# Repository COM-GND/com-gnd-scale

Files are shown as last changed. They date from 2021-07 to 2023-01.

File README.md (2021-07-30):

COM GND Logo

# COM-GND SCALE

This hardware project is under active development in conjunction with the [GND-CTRL](https://github.com/COM-GND/gnd-ctrl-web-app) software interface.

---

### WARNING: ALPHA STAGE PROJECT

This project is unstable and undergoing active development.

---

## Hardware Stack

- [Esp32 DevkitC](https://www.amazon.com/Espressif-ESP32-DevKitC-32UE-Development-Board/dp/B087T94ZH9): Microcontroller with onboard BLE

## Development

This is a [Platform.io](https://platformio.org/) based project using the Arduino framework.

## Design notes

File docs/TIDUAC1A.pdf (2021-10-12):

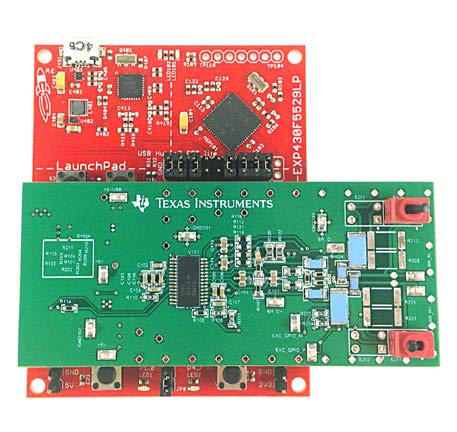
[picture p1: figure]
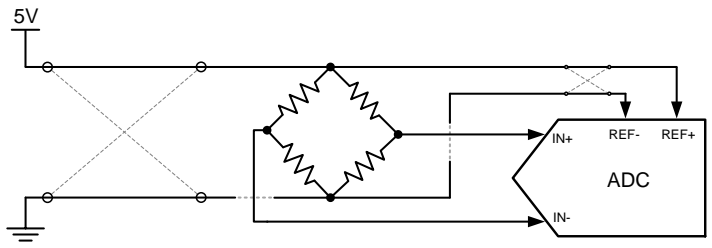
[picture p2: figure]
ADC; REF-; REF+

An IMPORTANT NOTICE at the end of this TI reference design addresses authorized use, intellectual property matters and other important disclaimers and information.
TINA-TI is a trademark of Texas Instruments
WEBENCH is a registered trademark of Texas Instruments
TIDUAC1A-July 2015-Revised February 2019 | Precision Weigh-Scale Reference Design with AC Bridge Excitation | 1
| Copyright © 2015, Texas Instruments Incorporated

Christopher Hall

## TI Designs – Precision: Verified Design

# High-Resolution, Low-Drift, Precision Weigh-Scale Reference Design with AC Bridge Excitation

TI Designs – Precision are analog solutions created by TI’s analog experts. Verified Designs offer the theory, component selection, simulation, complete PCB schematic & layout, bill of materials, and measured performance of useful circuits. Circuit modifications that help to meet alternate design goals are also discussed.

This precision weigh-scale reference design achieves greater than 50,000 noise-free counts of resolution over a wide temperature range. Offset and offset drift errors are nearly eliminated by an ac-excited, ratiometrically measured resistor bridge. This design takes advantage of the high-resolution ADS1262 delta-sigma ADC.

Design Resources
Design Archive (http://www.ti.com/tool/tipd188) | All Design files
TINA-TI™ (http://www.ti.com/tina-ti) | SPICE Simulator
ADS1262 (http://www.ti.com/product/ads1262) | Product Folder
TS5A21366 (http://www.ti.com/product/TS5A21366) | Product Folder
MSP-EXP430F5529LP (http://www.ti.com/tool/MSP-EXP430F5529LP) | Tool Folder

Ask The Analog Experts (http://e2e.ti.com/)
WEBENCH® Design Center (http://www.ti.com/webench)
TI Designs – Precision Library (http://www.ti.com/ww/en/analog/precision-designs/index.html)

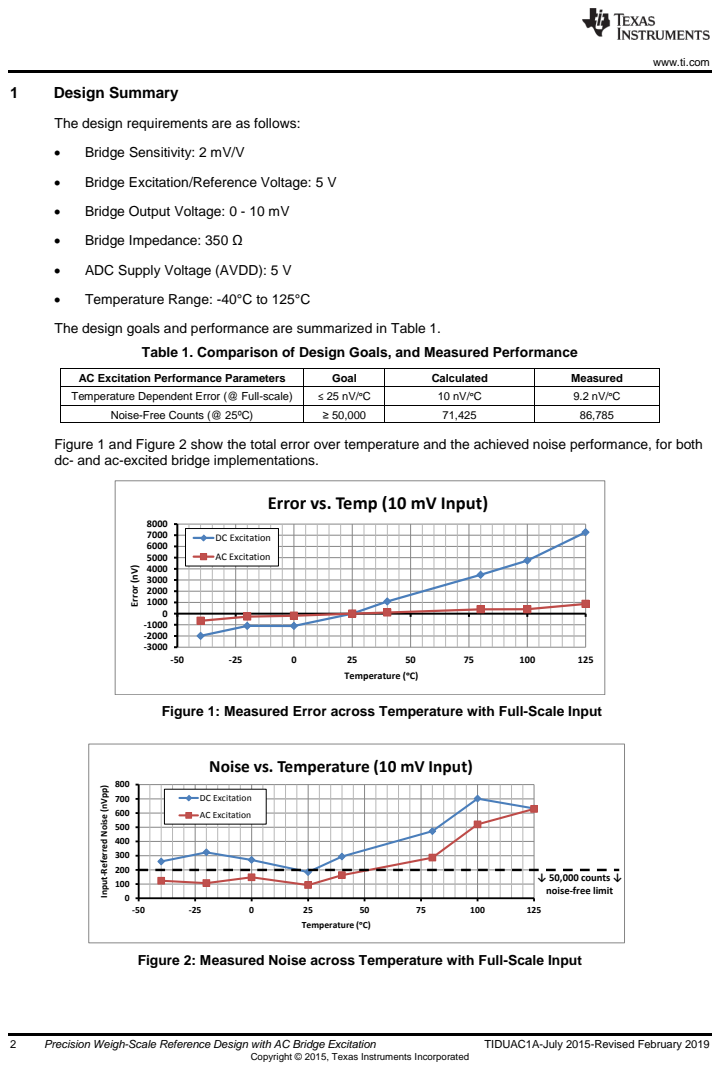
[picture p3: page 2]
Precision Weigh-Scale Reference Design with AC Bridge Excitation; TIDUAC1A-July 2015-Revised February 2019; Error (nV); Temperature (ᵒC); DC Excitation AC Excitation

www.ti.com

1 Design Summary
The design requirements are as follows:
• Bridge Sensitivity: 2 mV/V
• Bridge Excitation/Reference Voltage: 5 V
• Bridge Output Voltage: 0 - 10 mV
• Bridge Impedance: 350 Ω
• ADC Supply Voltage (AVDD): 5 V
• Temperature Range: -40°C to 125°C
The design goals and performance are summarized in Table 1.

Table 1. Comparison of Design Goals, and Measured Performance

AC Excitation Performance Parameters | Goal | Calculated | Measured
Temperature Dependent Error (@ Full-scale) | ≤ 25 nV/ᵒC | 10 nV/ᵒC | 9.2 nV/ᵒC
Noise-Free Counts (@ 25ºC) | ≥ 50,000 | 71,425 | 86,785

Figure 1 and Figure 2 show the total error over temperature and the achieved noise performance, for both
dc- and ac-excited bridge implementations.

Error vs. Temp (10 mV Input)

DC Excitation
AC Excitation

Figure 1: Measured Error across Temperature with Full-Scale Input

Noise vs. Temperature (10 mV Input)

Input-Referred Noise (nVpp)

↓ 50,000 counts ↓
noise-free limit

Figure 2: Measured Noise across Temperature with Full-Scale Input

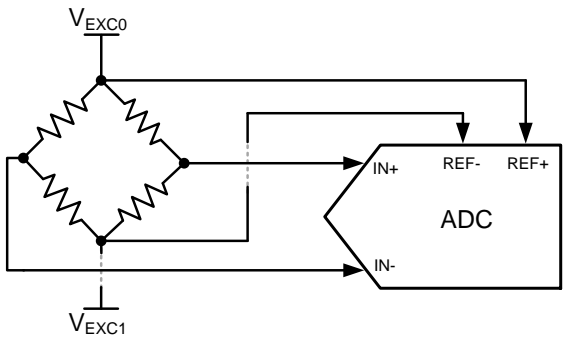
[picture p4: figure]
ADC; REF-; REF+; VEXC0; VEXC1

TIDUAC1A-July 2015-Revised February 2019 | Precision Weigh-Scale Reference Design with AC Bridge Excitation | 3

### 2 Theory of Operation

### 2.1 Overview of Bridge Measurements

The most common technique to convert weight into an electrical signal is to use a resistive load cell configured as a Wheatstone bridge. In this configuration, one or more of the resistors change value in proportion to the load (weight) applied. To measure this effect, an excitation voltage (or current) source is applied across the top and bottom of the bridge and the output signal is measured as the differential voltage across the middle nodes, as shown in Figure 3.

Figure 3: Wheatstone Bridge In practice, load cells are specified with a known sensitivity (or rated output) and a rated capacity (maximum load). The sensitivity is specified by the ratio of the output voltage produced per 1-V excitation voltage (given in units of mV/V) with the rated capacity load applied. The full-scale output voltage of the load cell is then calculated by Equation 1.

# VBBBBBB_FF(m ) = SSSSSSSSSSS

m

# V ∙ VEEE(V) ( 1 )

For example, a 2 mV/V load cell excited with 5 V will have a full-scale output voltage of 10 mV. It is important to note that the magnitude of the output signal is directly proportional to the magnitude of the excitation voltage and applied load. In general, the output voltage for any other applied load will scale linearly from no load to the maximum load. (Bridge linearization techniques may be used increase the bridge linearity, but this topic is outside the scope of this TI Design).

### 2.1.1 Ratiometric Bridge Measurements

The voltage-excited bridge is connected to the ADC using a ratiometric connection, as shown in Figure 4.

Figure 4: Ratiometric Bridge Configuration NOTE: The excitation voltage (VEXC = VEXC0 – VEXC1) does not necessarily need to be referenced to ground. This allows for level-shifting of the bridge common-mode voltage.

Excitation Voltage, VEXC

+
Load Cell
Output Voltage, VOUT

R1
R3 R2

R4

4 | Precision Weigh-Scale Reference Design with AC Bridge Excitation | TIDUAC1A-July 2015-Revised February 2019

In this configuration, the bridge excitation voltage is shared with the ADC’s reference voltage. Any changes in the bridge excitation voltage, due to temperature drift or noise, will affect both the input signal and reference proportionately. Therefore, the ADC conversion results (codes) remain unaffected by changes in the excitation/reference voltage, as shown by Equation 2.

# CCC ∝

# VBBBBBB

VR

# = (% RR L ) ∙ (SSSSSSSSSSS) ∙ VR

VR

# = (% RR L ) ∙ (SSSSSSS ) ( 2 )

Another benefit of ratiometric bridge measurements is that reference noise is reduced because the reference noise is common to both the ADC and reference inputs. To the degree that the reference noise seen by the ADC input and reference terminals match, reference noise is ratiometrically removed from the ADC conversion results, as Equation 2 shows. Therefore, input and reference filters ought to be matched to provide the best reference noise rejection (discussed in SBAA201). (http://www.ti.com/litv/pdf/sbaa201)

### 2.2 Input Chopping Overview

Chopping is a form of averaging that samples a differential input from both directions and averages the conversion results. Figure 5 shows the two phases of an ADC sampling a chopped input, with system offset voltages modelled as VOS1 and VOS2.

Figure 5: Input Chopping Concept

Many high-resolution ADCs, such as the ADS1262, integrate input chopping into the device to reduce the offset and offset drift of the ADC. By performing the chopping operation, any systematic offsets that occur after the chopping circuitry (primarily the ADC’s offset) are removed, as shown by equation 3.

# VAA = VAA (PPP P1) − VAA (PPP P2)

2 | = (VII + VO 1 + VO 2) − (−VII − VO 1 + VO 2)
2 | = VII + VO 1 ( 3 )

Systematic offsets that occur before the input chopping circuitry (represented by VOS1) are not removed by chopping. These offsets are seen as part of the differential input signal and are only removed by offset calibration. However, slowly changing offsets that occur after the chopping (represented by VOS2) are dynamically removed.
NOTE: This design does not use the ADC’s input chopping feature. This discussion is provided only to introduce the input chopping concept and how it works, as a prerequisite for understanding ac bridge excitation.

ADC

ADC

+
–

+
–

VOS2

VIN

VOS2

VADC

+
–

VADC

+
–

IN+

IN-

IN+

IN-

PHASE 1

PHASE 2

VOS1

+
–

+
–

VIN

VOS1

+
–

+
–

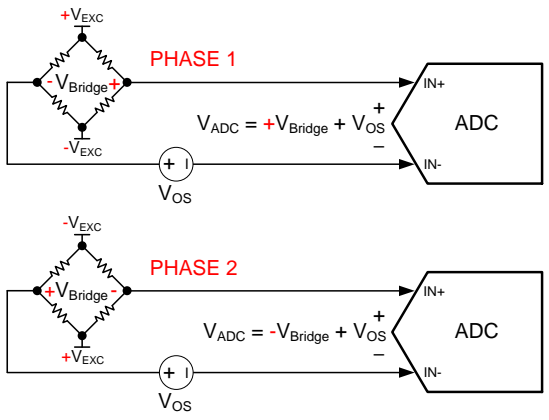
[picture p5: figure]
ADC; +VEXC; VADC = +VBridge + VOS; PHASE 1; -VBridge+; -VEXC; VADC = -VBridge + VOS; PHASE 2; +VBridge -; VOS

TIDUAC1A-July 2015-Revised February 2019 | Precision Weigh-Scale Reference Design with AC Bridge Excitation | 5

### 2.2.1 Overview of AC Bridge Excitation

AC bridge excitation is an extension of input chopping. While input chopping only reduces the offset and offset drift of the ADC; ac bridge excitation reduces the offset and offset drift of the whole measurement system. AC bridge excitation performs the same operation as ADC input chopping, but performs the chopping directly on the bridge sensor. Recalling the observation from Section 2.2 that offsets after the chopping stage are removed, it is then most beneficial to place the chopping circuitry as close to the sensor output as possible. By doing so, the measurement system’s offset is almost completely removed from the measurement results.
AC bridge excitation does not excite the bridge with an actual ac signal (as the name would seem to imply). AC bridge excitation is performed by applying a dc excitation voltage to the bridge and alternating the polarity of the excitation voltage, as seen in Figure 6.

Figure 6: AC Bridge Excitation Concept

Equation 4 shows that ac bridge excitation removes offsets in the same way that input chopping removes offsets. The only difference between these two methods is the location of the chopping/switching.
( | ) ( | )

Bridge

ADC | ADC | Bridge | OS | Bridge | OS
ADC | V V | PHASE | V | PHASE | V | V | V | V
V | = + | − − | + = − = | 2 | 2
( | 1) | ( | 2) | ( 4 )

The offset voltage, VOS, of Figure 6 comprises all offset voltages in the measurement system. These may include the ADC’s offset, parasitic thermocouples (to be discussed in Section 2.3), or any offsets added by signal conditioning circuitry. Therefore, as long as VOS changes slowly (with respect to the chopping frequency) the system’s offset and offset drift are dynamically removed.
The effect of ac bridge excitation is much like continuously measuring and applying a system offset calibration (removing the overall offset of the measurement system, as opposed to input chopping, which only removes the ADC’s contribution to the system offset).

Note that applying the AC bridge excitation technique will require the reference connections to be switched to keep the reference voltage (as seen by the ADC) positive.

6 | Precision Weigh-Scale Reference Design with AC Bridge Excitation | TIDUAC1A-July 2015-Revised February 2019

### 2.3 Overview of Parasitic Thermocouples

Thermocouples are a very useful and common type of temperature sensor. They are formed by junctions of dissimilar metals. When these junctions are exposed to temperature gradients, a thermal electromotive force (EMF), or Seebeck voltage, is produced as a function of the temperature gradient and the metals involved. When thermocouples are used intentionally, they can provide accurate temperature sensing over a wide temperature range and at a low cost. However, unintentional thermocouples are just as common (if not more) and can greatly reduce the accuracy of precision sensing applications. When used unintentionally, we refer to these thermocouples as parasitic thermocouples.
Refer to previous TI Design documents (SLAU509 (http://www.ti.com/lit/pdf/SLAU509) or TIDU574) (http://www.ti.com/lit/pdf/tidu574) for more detailed descriptions and overviews of thermocouple theory.
Parasitic thermocouples exist in many locations within a circuit. Most connections to the printed circuit board (PCB) will involve multiple dissimilar metals such as copper, tin, lead, nickel, gold, silver, aluminum, etc... The larger the Seebeck coefficient (or sensitivity, expressed in μV/ᵒC) between these junctions, the larger the offset voltage that can be introduced into the circuit as a temperature gradient is formed. The typical thermocouple sensitivity of most dissimilar metals will have a Seebeck coefficient in the range of a few microvolts per degree Celsius (μV/ᵒC). However, thermocouples with sensitivities >500 μV/ᵒC are possible with Copper-Copper Oxide junctions (caused by oxidation).
Parasitic thermocouples add to the offset and offset drift of the measurement system and may significantly degrade the overall system accuracy.

### 2.3.1 Reducing the Effects of Parasitic Thermocouples

PCB layout can reduce the effects of parasitic thermocouples. Symmetrical PCB layouts and differential measurements may help to match parasitic thermocouples and cancel any common-mode offsets. The use of a large (solid) ground plane can also act as a heat sink to remove thermal gradients. By keeping dissimilar metal junctions at a constant temperature, the parasitic thermocouple will not induce any additional Seebeck (offset) voltage because of the law of intermediate metals.
Calibration may also be performed to correct for these offsets under certain conditions; however, dynamically changing environments may result in dynamic offsets, which are difficult to correct for by calibration alone. Even when calibrations are performed at multiple operating temperatures, the effect of parasitic thermocouples may still be observed as an offset drift over temperature.
AC bridge excitation is one of the best methods to remove the effects of parasitic thermocouples. Parasitic thermocouples appear after the chopping stage; therefore, their offset is continuously removed. This is the advantage of ac bridge excitation, as compared to offset calibration, which can only remove the initial offset.

### 2.3.2 Other Causes of Offset and Offset Drift

Parasitic thermocouples are just one example of an offset voltage source with temperature dependence. Another common source of offset voltage and offset drift results from input bias currents, namely input offset currents or differential input currents, when the input bias currents of a differential input pair are mismatched. An offset voltage forms when the differential bias current flows through any input-attached impedance, such as an input filter. The offset voltage will be proportional to the current and impedance, and both of these parameters (current and impedance) will typically have temperature dependence. Additionally, offset and offset drift-like behaviors have been shown (reference) (http://e2e.ti.com/blogs_/b/precisionhub/archive/2013/09/23/why-should-i-give-a-flux) to result from solder flux residues remaining from the PCB assembly process. There residues create parasitic conduction paths within the circuit and result in unpredictable behavior.

TIDUAC1A-July 2015-Revised February 2019 | Precision Weigh-Scale Reference Design with AC Bridge Excitation | 7

### 3 Component Selection and Configuration

### 3.1 ADC Selection – ADS1262 (or ADS1263)

The ADC is the critical component in most measurement systems. While all components may affect the overall measurement system performance, the system accuracy is unlikely to exceed the performance of the ADC. Hence, the ADC is typically selected first.
To determine the resolution required by the measurement system, the full-scale output voltage of the bridge is divided by the desired scale resolution specified in counts, as shown in Equation 5. (The scale requirement is 50,000 counts in this example).

# R RR R R RR = 10 m 50,000 = 200 → log2(50,000) = 15.6 b ( 5 )

The measurement system must be able to accurately resolve signals of at least 200 nV, or approximately15.6 bits. However, in practice, an ADC of much higher resolution must be used to account for the loss of dynamic range that occurs when the input signal is not scaled (level shifted and amplified) to match the ADC’s input range. A 24-bit delta-sigma ADC is usually selected for this type of application.
The ADS1262, a 32-bit delta-sigma ADC, was chosen for this design for its low-noise performance and integrated Programmable Gain Amplifier (PGA). The ADS1262 achieves the resolution required for high-end weigh-scale applications. Additionally, the ADS1262 provides General Purpose Input/Outputs (GPIOs) which may be used to control the switches for ac bridge excitation, a programmable settling delay time that allows large input step changes to settle prior to beginning conversions, and a reference polarity switch that makes it easier to implement ac bridge excitation.

### 3.1.1 Programmable Gain Amplifier (PGA) Configuration

The ADS1262’s integrated low-noise PGA provides gains up to 32 V/V. The highest gain setting, that does not exceed the input voltage range requirements, will typically provide the best noise performance. In this design, the full-scale bridge output voltage is 10 mV; therefore, a gain of 32 V/V may be used. (See Table 4 in the ADS1262 data sheet (SBAS661). (http://www.ti.com/lit/pdf/SBAS661)
NOTE: The ADC’s full-scale range scales with both reference voltage and gain. The full-scale range of the ADS1262 (as used in this design), is shown in Equation 6.

# F = ±VR

# PPP = ±(5 V) 32 V/V = ±156 m ( 312 m ) ( 6 )

NOTE: Many weigh-scale designs typically use gains higher than 32 V/V. However, it is important to note that increasing gain amplifies both the input signal and the amplifier’s noise. The low-noise PGA of the ADS1262 is capable of resolving much smaller signals than most other amplifier or PGA configured with higher gain.

### 3.1.2 Digital Filter Configuration

The default filter configuration for the ADS1262 is an FIR filter with a data rate of 20 SPS. This filter setting was used in this design because it provides simultaneous 50/60Hz line cycle rejection and single-cycle settling behavior. This configuration provides ADC resolutions down to 0.167 nVPP, as shown by Table 1 in the ADS1262 data sheet (SBAS661). (http://www.ti.com/lit/pdf/SBAS661)

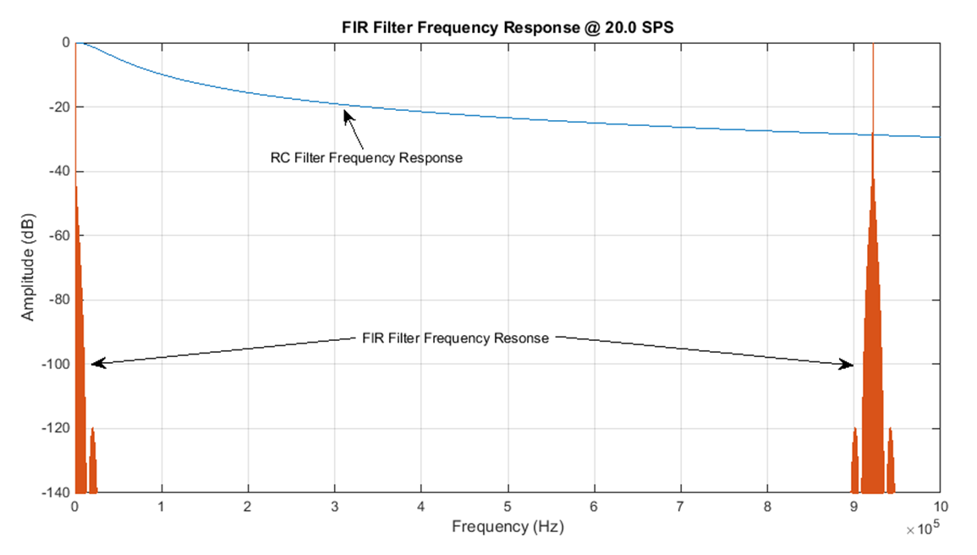
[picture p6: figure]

8 | Precision Weigh-Scale Reference Design with AC Bridge Excitation | TIDUAC1A-July 2015-Revised February 2019

### 3.2 Switch Selection – TS5A21366

The TS5A21366 is a dual single pole single throw (SPST) 0.75Ω analog switch used to control the bridge’s excitation voltage polarity (for ac bridge excitation). This switch was chosen for its voltage compatibility and low on-resistance. The digital logic level of the switch is compatible with the 5-V GPIO logic of the ADS1262, and the input allows for the 5-V bridge excitation voltage. The on-resistance of the bridge switch is important to consider in this application because a significant current flows through the bridge (approximately 15mA. The power dissipation of the bridge switch can cause device heating, as well as reduce the excitation voltage and signal magnitude of the bridge output The TS5A21366 is rated for currents up to 200 mA, making it well suited for this application.

NOTE: The TS5A21366 is only specified to operate from -40ºC to 85ºC and was not directly subjected to the forced ambient air temperatures during testing.

### 3.3 Passive Component Selection

### 3.3.1 Input and Reference Low-Pass Filters

The input and reference filters are first-order RC circuits. The main purpose of the input filter is for anti-aliasing. While this filter can also assist in reducing signal noise, the low-bandwidth digital filter provides the majority of the signal noise rejection; therefore, we are only concerned about using this filter for anti-aliasing.
The aliasing frequencies of concern are frequencies around the modulator sampling frequency, fMOD (for the ADS1262 fMOD = 921.6 kHz when using the internal oscillator). Note that the sampling frequency inside a delta-sigma ADC is much higher than the output data rate. The input signal is oversampled by the delta-sigma modulator and the output data rate is decimated by the digital filter.
The delta-sigma ADC’s digital filter does not provide much noise attenuation around the sampling frequency. Signals in this region are aliased back into the filter’s low-frequency passband. Typically, a single-pole RC filter is adequate to attenuate signals in this region. Figure 7 shows an example of an RC filter with a cutoff frequency of 33.8 kHz and ~29 dB of attenuation near the ADC’s sampling frequency.

Figure 7: 20 SPS FIR Filter Frequency Response Refer to Section 10.1.5.1 in the ADS1262 Data Sheet (SBAS661) (http://www.ti.com/litv/pdf/sbas661) for additional information on aliasing.

TIDUAC1A-July 2015-Revised February 2019 | Precision Weigh-Scale Reference Design with AC Bridge Excitation | 9

### 3.3.2 X2Y™ Capacitors

X2Y™ capacitors were used for the RC low-pass filters. A single X2Y™ capacitor can replace multiple capacitors required for common-mode and differential filtering. In addition to saving board space, these capacitors have low equivalent series inductance (ESL) and excellent common-mode capacitor matching, required to prevent the conversion of common-mode signals to differential signals.
NOTE: Typically common-mode filters become mismatched because of high capacitor tolerances. Higher common-mode signal frequencies are then filtered differently and result in a differential signal seen by the ADC inputs. This effect can also be reduced by ensuring that the differential filter has a lower cutoff frequency (~1/10th) than the common-mode filter’s cutoff frequency.

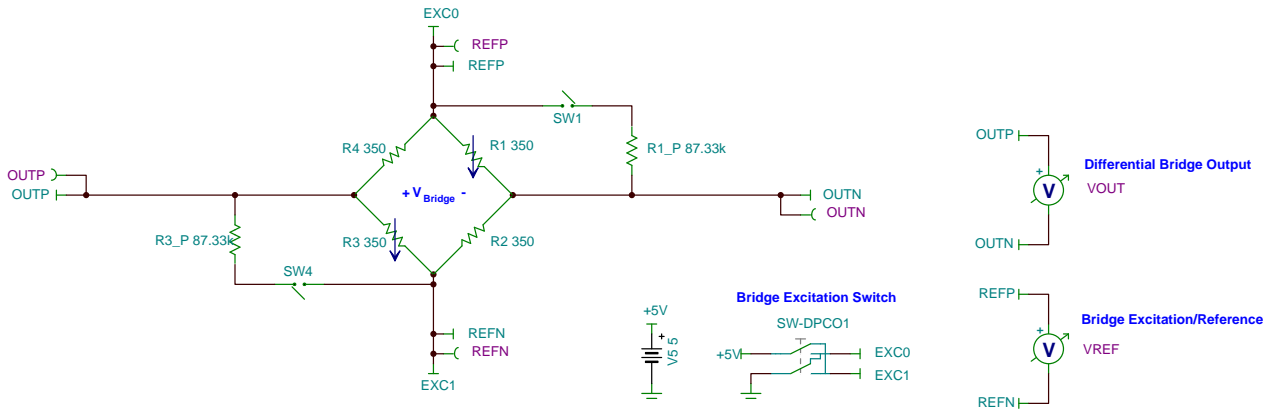
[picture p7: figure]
EXC0; EXC1; EXC0 EXC1; OUTN; OUTP; REFN; REFP; SW-DPCO1; VOUT; VREF; Differential Bridge Output; Bridge Excitation/Reference; Bridge Excitation Switch; + V Bridge -

10 | Precision Weigh-Scale Reference Design with AC Bridge Excitation | TIDUAC1A-July 2015-Revised February 2019

### 4 Simulations and Calculations

### 4.1 Load Cell Bridge Simulator Circuit

Figure 8 shows the TINA-TI™ circuit used to simulate the behavior of the load cell bridge.

Figure 8: Load Cell Bridge Simulator The load cell bridge simulator was designed to model the behavior of a load cell at “no load” and “max load” conditions. When SW1 and SW4 are open, the resistor bridge is balanced and the output voltage should be 0 V (no load condition). When SW1 and SW4 are closed, the resistor bridge is unbalanced and the output voltage should be 10 mV (max load condition with 2 mV/V sensitivity and 5-V excitation). Normally, the resistor changes resistance as a function of the load, but in this simulator circuit, a resistor is switched in to be parallel with the active bridge elements to model the changing resistance. The output voltage of the bridge in Figure 9 can be calculated using Equation 7.

2

2 | R R
V | R V | EXC
Bridge | ∆
+
∆ = − | ⋅ | ( 7 )

Where
- “VEXC ” is the bridge excitation voltage (5 V)
- “ ∆R ” is the change in resistance of R1 and R3 when SW1 and SW4 are closed.
Solving Equation 7 with VBridge = 10 mV, we find that ∆R ≈ -1.3972 Ω. Next we find the value of the parallel resistors (R1P and R3P) that produce an equivalent resistance of R + ∆R and find that parallel resistors of approximately 87.325 kΩ produce the desired outcome. The simulation confirms this result, with a full-scale bridge voltage of 9.97 mV. The 0.3% full-scale error is tolerable because most load cells will have a similar error (which is removed by performing full-scale calibration).

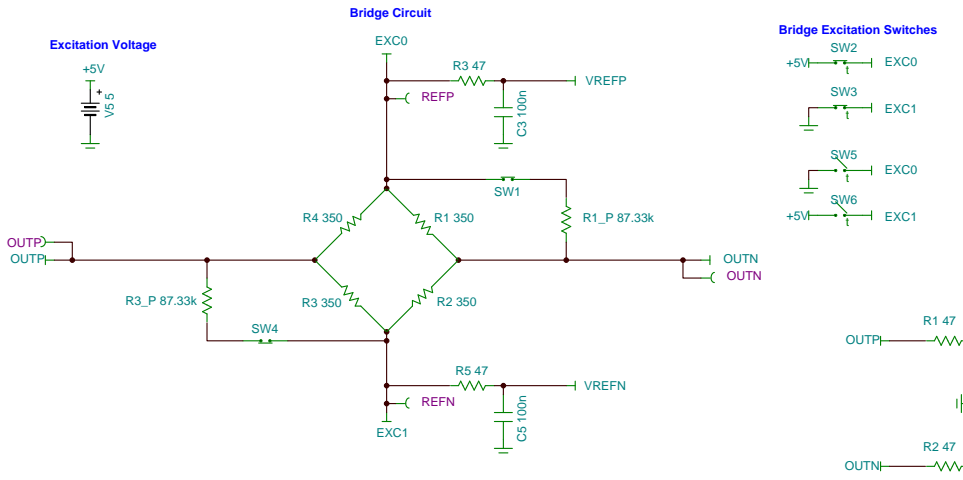
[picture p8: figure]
OUTN; OUTP; EXC0; EXC1; VREFP; VREFN; REFP; REFN; Bridge Excitation Switches; Excitation Voltage; Bridge Circuit
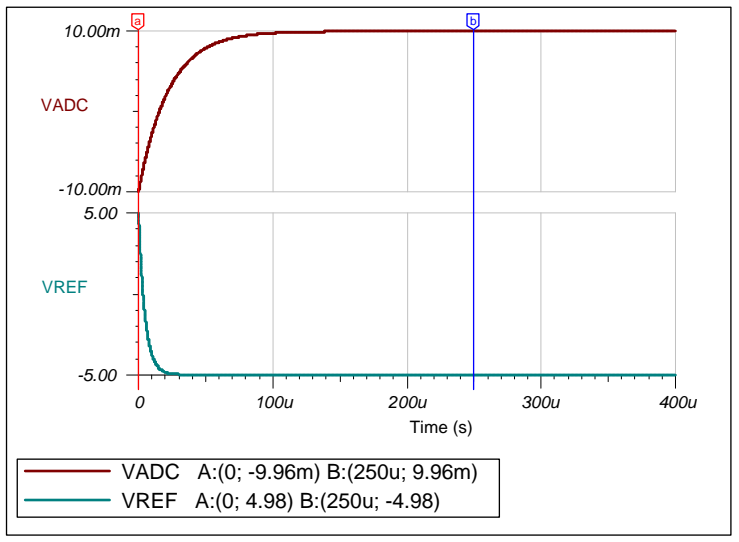
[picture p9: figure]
Time (s); VADC; VREF; VADC A:(0; -9.96m) B:(250u; 9.96m) VREF A:(0; 4.98) B:(250u; -4.98)

TIDUAC1A-July 2015-Revised February 2019 | Precision Weigh-Scale Reference Design with AC Bridge Excitation | 11

### 4.2 Load Cell Simulator Settling Time

Figure 9 shows the TINA-TI™ circuit used to simulate the settling time of the load cell.

Figure 9: Load Cell Bridge Simulator with Low-Pass Filters The circuit in Figure 9 has been slightly modified from Figure 8. Switches SW1 and SW4 are closed to set the bridge to full-scale, time-controlled switches are added to control the bridge excitation polarity, and the RC low-pass filters are included on the reference and bridge outputs.
At a certain time, the bridge excitation polarity is switched in a break-before-make scheme and the bridge output is monitored to observe the required settling time of the RC filter. Note that this settling time needs to be provided each time the ac bridge excitation switches polarity, prior to beginning the ADC conversion, which reduces the effective throughput of the ADC. The transient simulation, shown in Figure 10, shows the combined bridge and filter settling time (observed from the ADC’s input) to be approximately 250 μs.

Figure 10: Bridge Settling Time Transient Analysis Knowing the settling time of the bridge and input circuitry allows us to delay ADC conversions until the ADC’s input signal is settled. The ADS1262 allows for a programmable settling delay. Writing “0110b” to the DELAY[3:0] bits in the MODE0 register configures a 278 µs conversion start delay. See Section 9.4.3 (Programmable Time Delay) in the ADS1262 data sheet (SBAS661). (http://www.ti.com/lit/pdf/SBAS661)

OUTN

OUTP

VREFP

VREFN

V

+
VOUT

V

+
VREF

C1 100n C2 100n
V

+
VADC

Differential Bridge Output

Bridge Excitation/Reference

Differential ADC Input

12 | Precision Weigh-Scale Reference Design with AC Bridge Excitation | TIDUAC1A-July 2015-Revised February 2019

### 4.3 Effective System Data Rate

The effective system data rate, or throughput, is the rate at which ADC data can be read and processed. This data rate may be less than the programmed data rate of the ADC due to certain measurement delays. These delays are discussed for both the dc- and ac-excited bridge measurements.

### 4.3.1 Effective System Data Rate for DC-excited Bridge Measurements

In general, measurements in a dc-excited bridge are taken continuously. Therefore, the effective data rate is the same as the ADC’s configured data rate. Except, the first ADC conversion result includes some conversion latency to allow for the input circuitry to settle and to allow for the conversion results to propagate through the multiple digital filter stages. See Section 9.4.2 in the ADS1262 data sheet (SBAS661). (http://www.ti.com/lit/pdf/SBAS661)
Additionally, post-processing may request multiple ADC samples to calculate an averaged result, further reducing the effective data rate. Once all of these delays are combined, the resulting effective data rate is given by Equation 8.

# DR _EEE = 1

# D Y + ( S ) + (N − 1) DR NN

| ( 8 )
- “D ” is the programmed settling delay of the ADS1262 from the START signal (or command)

to the beginning of ADC conversions. This settling delay should be long enough to account for the analog RC filter settling time as simulated in Section 4.2.
- “ ( S )” is the ADC’s conversion latency for the first conversion period. This period is slightly longer than a normal data rate period to allow for digital delays required to start the conversion, calculate the calibrated results, and output the result. These delays are masked by pipelined operations when continuously converting.
- “DR NN” is the nominal output data rate of the ADC when continuously converting.
- “N” is the number of samples averaged in post-processing.

In this design, the ADS1262 was configured with the 20 SPS, FIR digital filter, and additional 278 µs delay. The time required to collect 16 samples is 802.5 ms, as shown by Equation 9.
1

# DR _EEE

# = D + ( S ) + (N − 1) DR NN

= 278 µ + 52.22 m + (16 − 1)

# (20 S S) = 802.5 m ( 9 )

### 4.3.2 Effective System Data Rate for AC-excited Bridge Measurements

The effective data rate for ac-excited bridge measurements is similar to the dc-excited case; however, the ADC conversion must be restarted every time the excitation voltage is reversed, resulting in additional conversion latency, as shown by Equation 10.

# DRA _EEE = 1

# 2 ∙ D + ( S ) + (N − 1) DR NN

| ( 10 )
- “N”, in this equation, is the number of samples taken each time the excitation voltage polarity is

switched.
In this design, the ac-excited bridge was measured with a total of 32 samples (16 samples each time the bridge excitation voltage was switched), resulting in a total collection time of 1605 ms (twice the time calculated in Equation 10).
NOTE: Software delays are assumed to be insignificant and neglected from Equations 8-10.

TIDUAC1A-July 2015-Revised February 2019 | Precision Weigh-Scale Reference Design with AC Bridge Excitation | 13

### 4.4 Total Error Analysis

The performance of this system depends mostly on the ADC’s performance. The ADS1262 error specifications can be taken from the data sheet (SBAS661) (http://www.ti.com/lit/pdf/SBAS661) and used to estimate the typical performance of this design. The main errors of interest are the noise, offset, offset drift, gain error, gain error drift, and integral nonlinearity (INL). The typical values for these errors were converted to parts per million (ppm) ratios, referenced to the ADC’s full-scale range, as shown in Table 2.
Table 2. Total ADC Error Calculations (Typical)
Typical ADC Errors | Error Before Calibration | Error After Calibration
Noise | 198.00 | (nVpp) | 0.63 | (ppm) | 0.63 | (ppm)
Offset (removed by ac excitation) | 10.9375 | (µV) | 35.00 | (ppm) | 0.16 | (ppm)
Offset Drift (removed by ac excitation) | 10.94 | (nV/ᵒC) | 5.78 | (ppm) | 5.78 | (ppm)
Gain Error | 0.005% | (%) | 1.00 | (ppm) | 0.01 | (ppm)
Gain Error Drift | 0.5 | (ppm/ᵒC) | 5.28 | (ppm) | 5.28 | (ppm)
INL | 3 | (ppm) | 3 | (ppm) | 3 | (ppm)
TOTAL DC Excitation Error Estimate (@ 10 mV) | | | 36.01 | (ppm) | 8.41 | (ppm)
| | | 11253 | nV | 2627 | nV
| | | 14.8 | (nV/ᵒC) | 14.8 | (nV/ᵒC)
TOTAL AC Excitation Error Estimate (@ 10 mV) | | | 6.17 | (ppm) | 6.09 | (ppm)
| | | 1928 | nV | 1903 | nV
| | | 10 | (nV/ᵒC) | 10 | (nV/ᵒC)

For each error calculation, the error was converted to an absolute voltage and then divided by 0.312 mV (the ADC’s full-scale range, as calculated in Equation 6). To estimate the absolute voltage error of a temperature-dependent error (offset drift and gain drift), the error must be multiplied by the temperature range (165ºC in this design). To estimate the absolute voltage error of a gain-related error (gain error and gain error drift), the error is multiplied by the ADC’s full-scale utilization factor (6.4%, or 10 mV divided by 0.312 mV). All errors were added together using the root sum of squares method to calculate the total error. The root sum of squares method assumes all errors are uncorrelated. When calculating the total error for the ac-excited bridge, the offset and offset drift errors were disregarded because they are removed by chopping.
The full Excel spreadsheet with additional error calculations can be found in the TIPD188 design file (TIDCAM8). (http://www.ti.com/lit/zip/tidcam8) ADC error calculations are also explained in a TI Precision Hub Blog (reference). (http://e2e.ti.com/blogs_/b/precisionhub/archive/2014/10/14/adc-accuracy-part-2-total-unadjusted-error-explained)
NOTE: These calculations only take into account the ADC error. The error contributions of the bridge sensor are not observed in this design. In the end-application, the load cell’s linearity and other error contributions should also be considered.
It is apparent from these calculations that the initial offset is the largest source of error. To reduce the offset error, either calibration or ac-excited bridge measurements must be implemented. The next largest sources of error are the offset drift and gain error drift. These errors can only be removed by re-calibrating, limiting the system’s temperature range, or performing ac bridge excitation to remove the offset drift. When ac bridge excitation is used, the ADC may not require calibration (or may not require re-calibration as often). However, in practical use, the load cell introduced errors may still require calibration.
From these calculations, the total measurement error of the ac-excited is estimated to be within 6 ppm (or about 2 µV) across the temperature range. Additionally, the error’s slope across temperature is linearly approximated to be about 15 nV/ᵒC (for the dc-excited bridge), and 10 nV/ᵒC (for the ac-excited bridge).

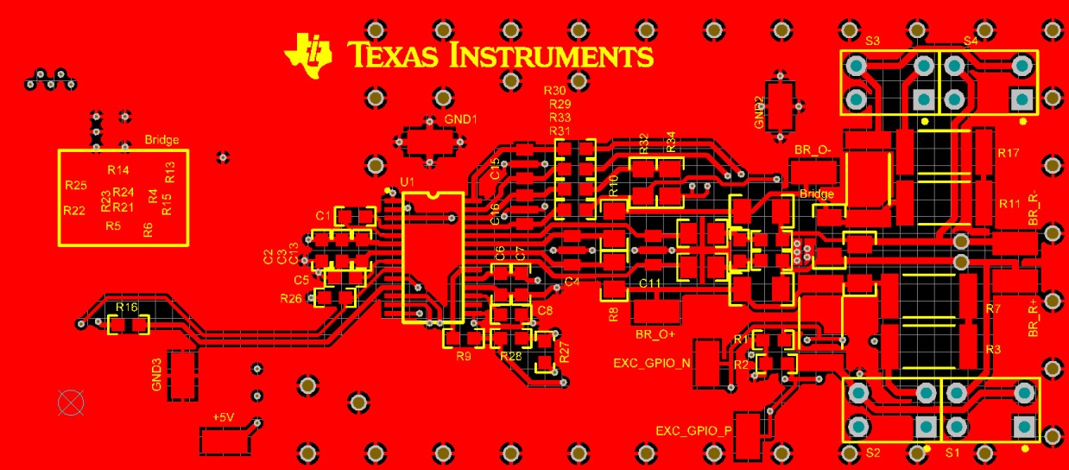
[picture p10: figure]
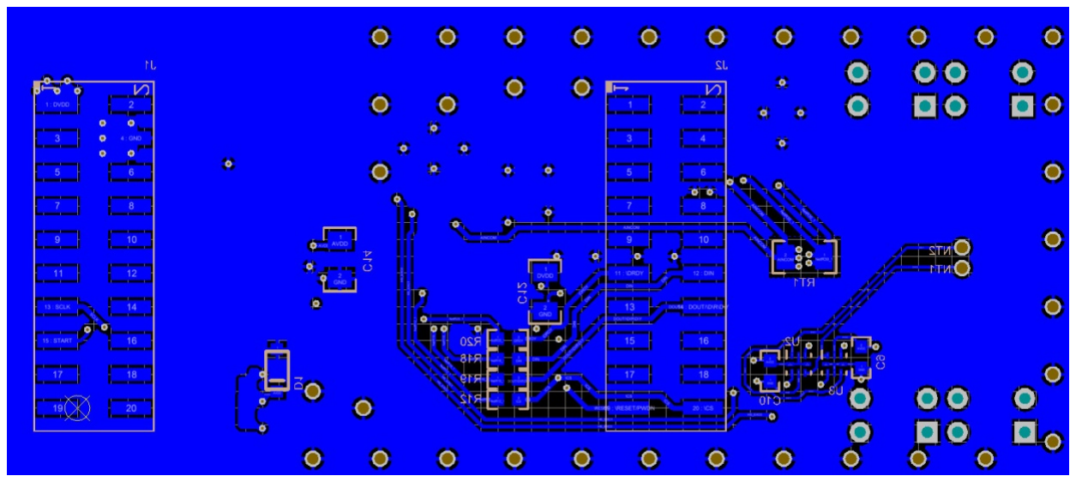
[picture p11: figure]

14 | Precision Weigh-Scale Reference Design with AC Bridge Excitation | TIDUAC1A-July 2015-Revised February 2019

### 5 PCB Design

The PCB schematic and bill of materials can be found in Appendix A.
The PCB is designed in a BoosterPack form factor to connect to TI’s LaunchPads. This particular BoosterPack was specifically designed to pair with the MSP430F5529 USB LaunchPad Evaluation Kit (MSP-EXP430F5529LP). (http://www.ti.com/tool/msp-exp430f5529lp) The LaunchPad provides the SPI interface to the ADS1262 and USB interface to the PC. For LaunchPad Hardware, refer to the MSP-EXP430F5529LP hardware design files (SLAR090). (http://www.ti.com/lit/zip/slar090)

### 5.1 PCB Layout

For optimal performance in any design, follow standard precision PCB layout guidelines including proper power supply decoupling close to all integrated circuits and adequate power and GND connections with large copper pours.
The top and bottom side PCB layout for this design are shown in Figure 11 (inner ground and power layers are not shown). This layout provides proper power supply decoupling and large ground pours on multiple layers. However, this PCB does not provide a symmetrical layout (as discussed in Section 2.3.1) to purposely allow for some parasitic thermocouples effects.

Figure 11: Altium PCB Layout (Top and Bottom Sides)

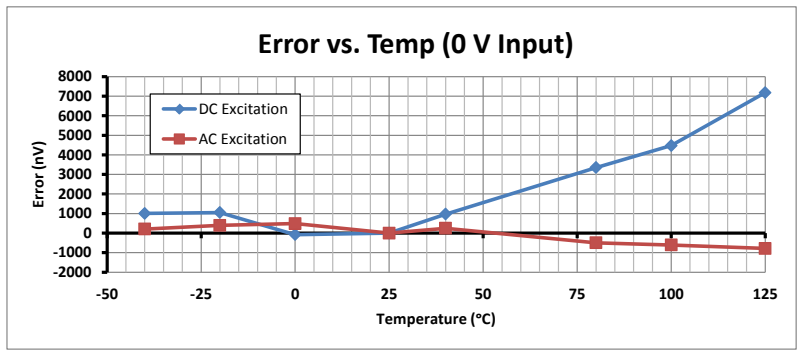
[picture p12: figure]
Error (nV); Temperature (ᵒC); Error vs. Temp (0 V Input); DC Excitation AC Excitation
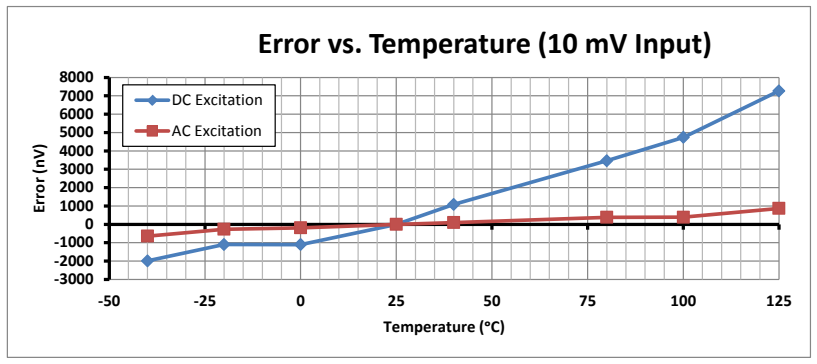
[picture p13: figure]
Error (nV); Temperature (ᵒC); Error vs. Temperature (10 mV Input); DC Excitation AC Excitation

TIDUAC1A-July 2015-Revised February 2019 | Precision Weigh-Scale Reference Design with AC Bridge Excitation | 15

### 6 Verification & Measured Performance

The full data collection procedure is outlined in Appendix C. Measurement data was collected for the 0V input and 10mV input cases. These two cases correspond to the 0% full-scale and 100% full-scale bridge outputs (or 0% and 6.4% full-scale range, with respect to the ADC input range, respectively). These cases typically showcase two extremes of the system performance:
1. Near 0% full-scale, measurement error is dominated by offset and INL errors.
2. Near 100% full-scale, measurement error is dominated by gain errors.

### 6.1 System Measurement Error

The dc and ac bridge excitation measurements were compared to the DMM measurement results to determine the measurement error. The difference between these results removes the offset drift of the resistor bridge circuit from the observed system error. Figure 12 shows the error of the dc- and ac-excited bridge measurements for a 0 V input signal.

Figure 12: Error vs. Temperature (0 V Input)

Similarly, Figure 13 shows the offset drift of the dc and ac-excited bridge measurements for a 10 mV input signal.

Figure 13: Error vs. Temperature (10 mV Input) The measurement error is much improved for the ac-excited bridge. Notice how the absolute values and temperature slope are both reduced. Also, notice that the measurement errors for both the 0V and 10mV inputs signal are very similar. In both of these cases, the offset and offset drift errors dominated the overall measurement error, which is what ac bridge excitation is able to remove.
The total system error for the ac-excited bridge (for a 10 mV input) is within ±1 µV. In Section 4.4, the total error calculated was 2 µV. These correlate well since the measurement error was centered around 25ºC.

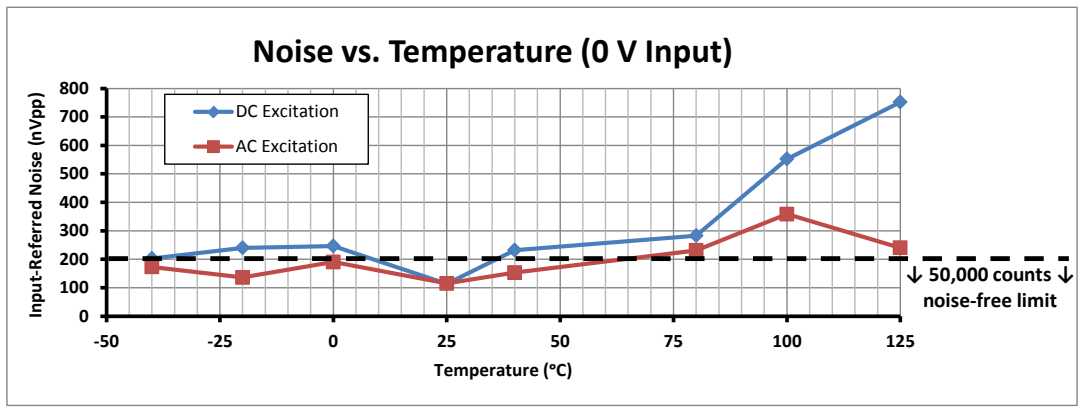
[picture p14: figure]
Input-Referred Noise (nVpp); Temperature (ᵒC); Noise vs. Temperature (0 V Input); DC Excitation AC Excitation; ↓ 50,000 counts ↓ noise-free limit
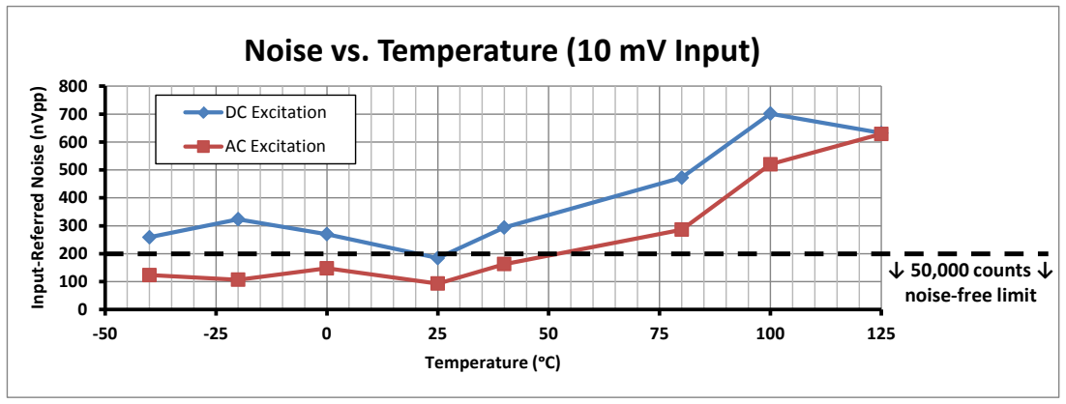
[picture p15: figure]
Input-Referred Noise (nVpp); Temperature (ᵒC); Noise vs. Temperature (10 mV Input); DC Excitation AC Excitation; ↓ 50,000 counts ↓ noise-free limit

16 | Precision Weigh-Scale Reference Design with AC Bridge Excitation | TIDUAC1A-July 2015-Revised February 2019

### 6.2 Noise Performance

The noise performance of the measurement system was observed across temperature and for both load conditions, as shown in Figures 14 and 15. The noise was measured as the maximum peak-to-peak voltage variation observed within 16 samples.
NOTE: For the ac-excited bridge measurements, two samples from opposite excitation polarities were first averaged to reduce the data from 32 samples to 16 (averaged) samples. The noise was then measured as the peak-to-peak voltage variation within the 16 (averaged) samples.

Figure 14: Noise vs. Temperature (0 V Input)

Figure 15: Noise vs. Temperature (10 mV Input) The averaged ac-excited bridge measurements show improved noise performance over the dc-excited bridge measurements and achieved 50,000 noise-free counts of resolution up to about 50 ºC. Noise performance did not degrade significantly from the 0 V to 10 mV input conditions because of the ratiometric measurement configuration, which provides reference noise cancellation.
The number of noise-free counts is calculated using Equation 11.

# N - f c = 10 m

# N ( nn) = 10 m

200 nn = 50,000 ( 11 )

For higher temperatures, increased thermal noise and higher component drift degrade the noise performance. However, weigh-scales are typically not operated up to such high temperatures.

TIDUAC1A-July 2015-Revised February 2019 | Precision Weigh-Scale Reference Design with AC Bridge Excitation | 17

### 7 Modifications

Many times analog circuit design involves trade-offs between various specifications. This section describes some of the trade-off decisions and possible modifications to this TI Design.

### 7.1 Effective Data Rate vs. Noise Performance

It is desirable to operate the measurement system at the fastest (effective) data rate that achieves the required noise performance of the measurement system. Noise performance degrades as the data rate is increased, because at higher data rates, the digital filter bandwidth increases and additional noise is observed in the ADC’s output codes. However, it is not just the programmed data rate that must be considered in this trade-off, but the effective data rate of the system. As seen by Equation 10, the effective data rate is a function of the ADC’s configured output data rate, the total settling and conversion delays, and the number of averages taken for each conversion result.
The portion of time which the ADC is converting must first be maximized to improve both the effective data rate and noise performance of the ADC. Therefore, it is important to keep settling times and conversion delays as small as possible, because the ADC is not converting during these delays. To reduce these delays, the cutoff frequencies of the analog input and reference filters can be relaxed. Even though increasing the cutoff frequencies would seem to degrade the noise performance, it does not have a significant impact at these low data rates, where the digital filter provides the bulk of the noise filtering. The cutoff frequencies of these filters can be increased to provide just enough anti-aliasing, and reducing the required settling time.
NOTE: The analog switch’s settling time may also be reduced by choosing a switch with a higher on-resistance (RON), but lower gate capacitance (Cg). However, the settling time of the switch is usually much smaller than the settling time of the input and reference filters.
Once the ADC conversion time has been maximized, the next option is to determine the number of additional samples to average during post-processing to further reduce the measurement system noise.

Averaging reduces the standard deviation of the noise by a factor of “√N” (“N” is defined in Section 4.3).

Note that the square-root factor provides diminishing returns on noise reduction as the number of averages is increased.

Instead of averaging additional samples (“N”) in post-processing, a better option may be to reduce the

ADC’s data rate. This has a similar effect to averaging multiple samples; however, it also benefits from the delta-sigma ADC’s noise shaping characteristic, resulting in lower noise than averaging in post-processing. For example, reducing the ADC’s data rate from 20 SPS to 2.5 SPS is essentially allowing the ADC to internally average an additional 4 samples per conversion. This typically provides better noise
performance than averaging 4 samples taken at the faster (20 SPS) data rate.

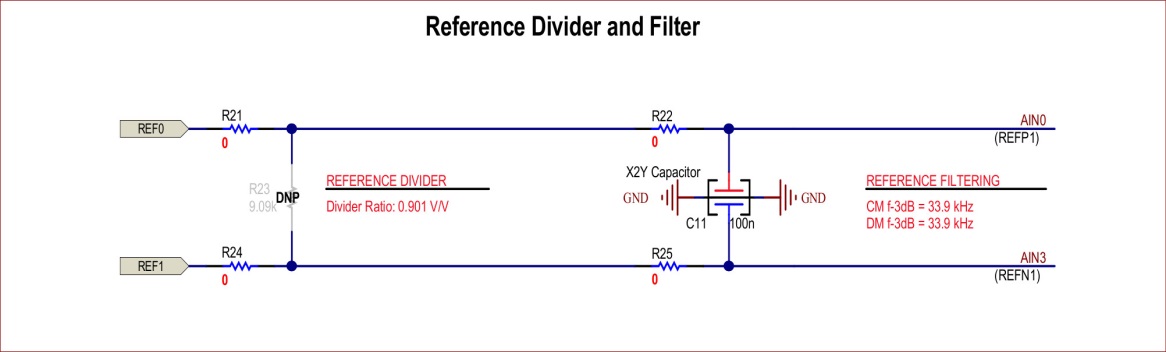
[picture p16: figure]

18 | Precision Weigh-Scale Reference Design with AC Bridge Excitation | TIDUAC1A-July 2015-Revised February 2019

### 7.2 Alternate Reference Filtering Scheme

The schematic for this design provided an optional resistor divider for the ADC’s external reference input. This divider was not used, and all reference filter series resistors (R21, R22, R24, and R25) were populated with 0-Ω resistors, as seen in Figure 16.

Figure 16: Reference Filter When the bridge is excited, the positive reference input is approximately 5 V (AVDD) and the negative reference input is approximately 0 V (AVSS). This leads to an average increase in the reference input bias current of about 50 nA (see the reference in the note below). This input current is also more sensitive to temperature variations. Therefore, any voltage drop across the reference resistors would reduce the reference voltage seen by the ADC, creating an additional gain error and gain error over temperature. This error was avoided by using 0-Ω resistors for the reference filter.
An alternate design option is to populate R21 and R24 with 91-Ω resistors and R23 with a 9.09-kΩ resistor to reduce the ADC’s reference voltage to 4.9 V. This small decrease in reference voltage is enough to avoid the higher reference input bias currents.
NOTE: Figure 33 in the ADS1262 data sheet (SBAS661) (http://www.ti.com/lit/pdf/SBAS661) shows the “Reference Input Current vs Reference Input Voltage”. The input bias current of the positive reference input increases when a 5 V reference is applied. Note that the x-axis step size in this plot is large and that that positive reference input current is well behaved until the reference is very close to 5 V.

### 7.3 Alternate ADC Design Options

The ADS1262 was chosen for this design because of its high performance and features that are well suited for implementing an ac-excited bridge measurement. The ADS1263 is a pin-for-pin and software compatible replacement that adds a secondary 24-bit delta-sigma ADC useful for redundant bridge measurements or other supporting functions within weigh-scale applications.
The ADS1232 and ADS1234 are part of another recommended family of 24-bit delta-sigma ADCs, well suited for bridge measurements. These devices are a lower cost alternative to the ADS126x devices, and are also capable of achieving high repeatability. These ADCs also allow for external references voltages up to AVDD + 0.1 V, which is very useful for implementing ratiometric 5-V excited bridge measurements. For low-power weigh-scale applications, the ADS1220 or ADS1231 24-bit delta-sigma ADCs are recommended. The ADS1220 is capable of fast power-up and duty-cycled operation. Both the ADS1220 and ADS1231provide a low-side bridge switch to power-down the bridge between conversions.

TIDUAC1A-July 2015-Revised February 2019 | Precision Weigh-Scale Reference Design with AC Bridge Excitation | 19

### 8 About the Author

Christopher Hall is an applications engineer in the Precision Delta-Sigma Data Converters group at Texas Instruments where he supports high-resolution industrial and seismic products and applications. Christopher received both his BSEE and MSEE from the University of Arizona.

### 9 Acknowledgements & References

Online Sources:
1. Trump, B. (May 2013). Chopper op amps and noise. http://www.edn.com/electronics-blogs/the-signal/4413341/Chopper-op-amps-and-noise
2. Thermal EMF and Offset Voltage. (April 2010). http://zone.ni.com/reference/en-XX/help/375472A-01/switch/thermal_voltages
3. Williams, Ian (September 2013). Why should I give a flux? http://e2e.ti.com/blogs_/b/precisionhub/archive/2013/09/23/why-should-i-give-a-flux
4. Agarwal, Vinay (October 2014). ADC Accuracy Part 2: Total unadjusted error explained http://e2e.ti.com/blogs_/b/precisionhub/archive/2014/10/14/adc-accuracy-part-2-total-unadjusted-error-explained (http://e2e.ti.com/blogs_/b/precisionhub/archive/2014/10/14/adc-accuracy-part-2-total-unadjusted-error-explained)

TI Documents:
5. ADS126x 32-Bit, Precision, 38-kSPS, Analog-to-Digital Converters with PGA and Voltage Reference. (SBAS661) (http://www.ti.com/lit/pdf/SBAS661)
6. Beckman, M., & Chioye, L. (June 2013). Simple Thermocouple Measurement Solution Reference Design. (SLAU509) (http://www.ti.com/lit/pdf/SLAU509)
7. Thermocouple AFE Using RTD or Integrated Temperature Sensor for Cold Junction Compensation (CJC) (October 2014). (TIDU574) (http://www.ti.com/lit/pdf/tidu574)
8. The ADS1232 and ADS1234: Complete Front End Solutions for Weigh Scales. White Paper. (June 2007). (SBAA154) (http://www.ti.com/lit/pdf/SBAA154)
9. Chioye, Luis. RTD Ratiometric Measurements and Filtering Using the ADS1148 and ADS1248. (March 2013). (SBAA201). (http://www.ti.com/litv/pdf/sbaa201)

www.ti.com

20 Precision Weigh-Scale Reference Design with AC Bridge Excitation TIDUAC1A-July 2015-Revised February 2019

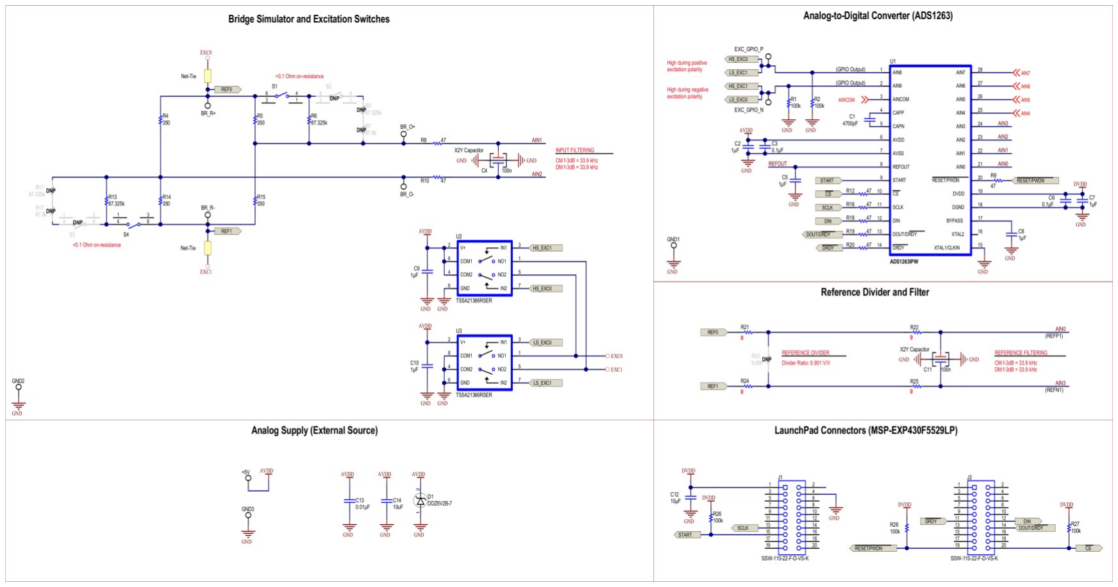
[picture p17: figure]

Copyright © 2015, Texas Instruments Incorporated

### Appendix A. PCB Schematic and Bill of Materials

A.1 Electrical Schematic

The schematic for this design can be seen in Figure A-1.

Figure A-1: Electrical Schematic

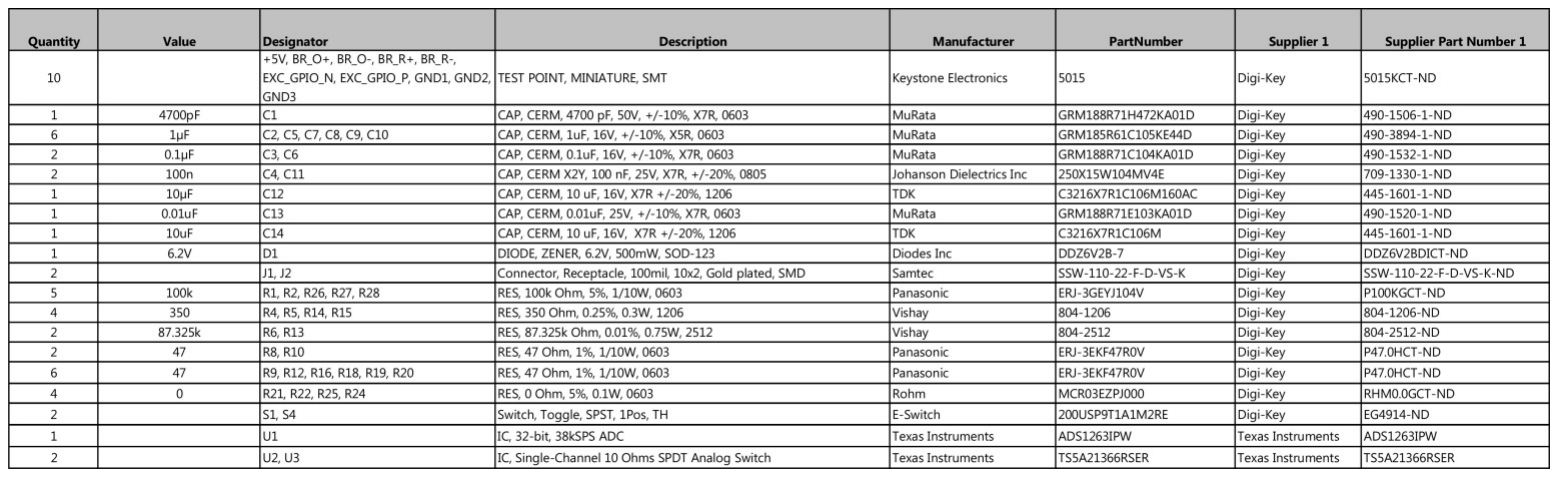
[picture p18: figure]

TIDUAC1A-July 2015-Revised February 2019 | Precision Weigh-Scale Reference Design with AC Bridge Excitation | 21

A.2 Bill of Materials
The bill of materials for this circuit can be seen in Figure A-2.

Figure A-2: Bill of Materials

22 | Precision Weigh-Scale Reference Design with AC Bridge Excitation | TIDUAC1A-July 2015-Revised February 2019

### Appendix B. Software

The entire Code Composer Studio (CCS) (http://www.ti.com/tool/ccstudio) project can be found in the TIPD188 design files (TIDCAN1). (http://www.ti.com/lit/zip/tidcan1) These files may also be referenced for ADS1262 example code.
B.1 Measuring the External Reference Voltage with the ADS1262
This code sequence provides a method to approximately measure an external reference voltage. It assumes an accurate knowledge of the internal reference voltage and a stable supply voltage. The supply voltage must be used as a reference voltage when the external reference voltage is greater than internal reference voltage
The ADS1262 first measures the supply voltage (divided by 4) with respect to the internal reference. The internal reference voltage may either be assumed to be 2.5 V, or it may be measured (externally) for better accuracy. Once the supply voltage is known, the external reference is measured with respect to the supply reference (the ADS1262 reference MUX may select the supply voltage as the reference).

static inline double get_reference(uint8_t print_output)
{
uint8_t WriteRegData; | //Stores the register write values
int32_t AdcOutput = 0;
const uint8_t Gain = 1;
double VoltageReading;
const double IntRefVolt = 2.49906; static double SupplyRefVolt = 5;
static double ExtRefVolt = 5;
WriteRegData = MUXP_AVDD | MUXN_AVSS;
ADS126xWriteRegister(INPMUX, 1, &WriteRegData);
WriteRegData = RMUXP_INTP | RMUXN_INTN;
ADS126xWriteRegister(REFMUX, 1, &WriteRegData); //Read one conversion
set_adc_START(1);
WaitForDRDY();
set_adc_START(0);
AdcOutput = ADS126xReadData(6, 1);
VoltageReading = (double) AdcOutput * IntRefVolt / ((double) Gain * exp2(29)); SupplyRefVolt = VoltageReading; //VREF = previous supply reading
WriteRegData = MUXP_AIN0 | MUXN_AIN3;
ADS126xWriteRegister(INPMUX, 1, &WriteRegData);
WriteRegData = RMUXP_AVDD | RMUXN_AVSS;
ADS126xWriteRegister(REFMUX, 1, &WriteRegData); //Read one conversion
set_adc_START(1);
WaitForDRDY();
set_adc_START(0);
AdcOutput = ADS126xReadData(6, 1);
VoltageReading = (double) AdcOutput * SupplyRefVolt / ((double) Gain * exp2(31)); ExtRefVolt = VoltageReading;
return ExtRefVolt;
}
| Figure B-1: Code Snippet

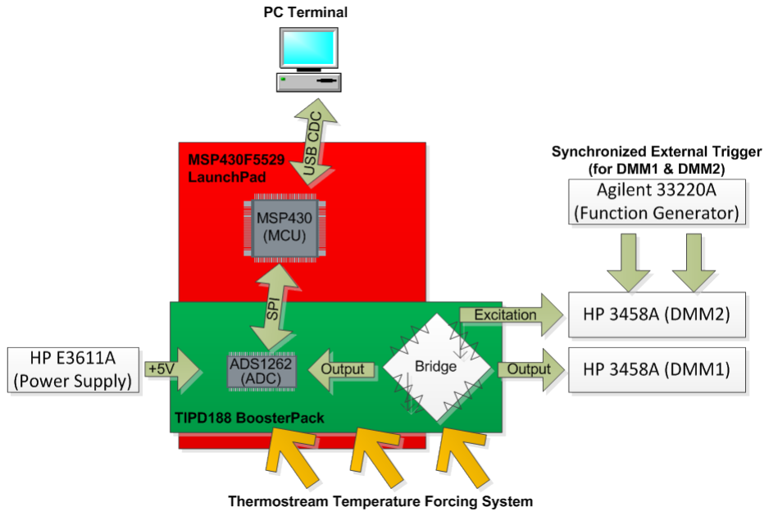
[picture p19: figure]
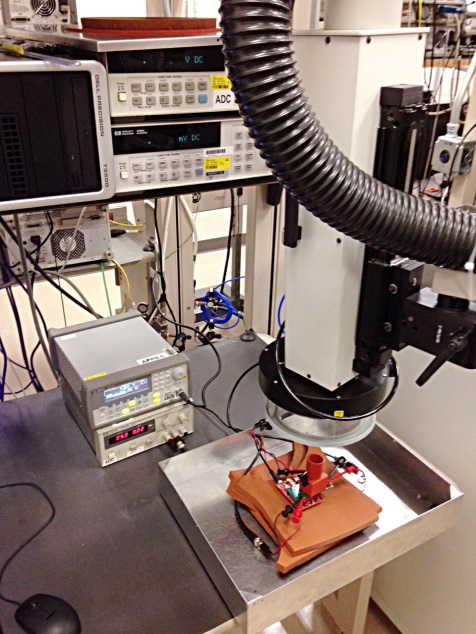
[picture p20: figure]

TIDUAC1A-July 2015-Revised February 2019 | Precision Weigh-Scale Reference Design with AC Bridge Excitation | 23

### Appendix C. Test & Calibration Procedure

An Excel document was used to post-process and analyze the data. This Excel file is included in the TIPD188 design files (TIDCAM8) (http://www.ti.com/lit/zip/tidcam8) for reference.

### 9.1 Overview of Test Setup

The PCB (TIPD188 BoosterPack) connects to the MSP430F5529 LaunchPad, as shown in Figure C-1. The LaunchPad provides the SPI and PC interfaces to collect and display the ADC bridge measurement data to the PC.
The PCB (TIPD188 BoosterPack) is placed under a thermostream temperature controller and the bridge output is measured across temperature (-40°C to +125°C), with and without utilizing ac bridge excitation. The data is post-processed and compared to the digital multimeter (DMM) measurements to determine the relative bridge measurement errors, with dc bridge excitation and ac bridge excitation technique
NOTE: The term “dc bridge excitation” indicates that the bridge was measured without ac excitation. In this case, the bridge output is only measured once, without switching the bridge’s excitation voltage polarity. The digital multimeter (DMM) measurements are required to provide a standard reference value for the ADC measurements, because the bridge resistors and bridge output will also drift over temperature. However, we only want to observe how much the ADC measurement results drift over temperature; not how much the bridge output voltage drifts over temperature.
NOTE: The DMMs measure both the bridge excitation voltage and bridge output voltage (DMM1 measures the bridge output and DMM2 measures the bride excitation voltage). Since a single DMM cannot measure the bridge ratiometrically, both measurements are needed to determine the ADC’s ideal output code. The accuracy of the DMMs is crucial for determining the ADC’s accuracy; therefore, high resolution DMMs, such as the HP 3458A, are required for this test. The ADC and DMM measurements are also separately calibrated to provide matching results at room temperature. Offset and gain calibration are only performed at this single temperature-point so that ADC and DMM mismatches are only the effect of temperature-related offset drifts. The DMM must also measure the ac-excited bridge with both excitation voltage polarities to remove offsets in the path from the bridge output to the DMM input.

Figure C-1: Test System Block Diagram (Left) and Test Bench Setup (Right)

24 | Precision Weigh-Scale Reference Design with AC Bridge Excitation | TIDUAC1A-July 2015-Revised February 2019

### 9.2 Calibration and Measurement Procedure

System offset and gain calibrations were performed once at room temperature for both the ADC and DMM results. Calibration correction calculations were only performed during data post-processing. The ADC calibration registers were configured to their respective default values. Overall three separate sets of calibration coefficients were measured and applied during post-processing; one set per measurement type. The three bridge measurement types are:
A. Measuring the dc-excited bridge with the ADC. This is the traditional bridge measurement technique that is measured here to acquire a baseline performance specification.
B. Measuring the ac excited bridge with the ADC. This is the bridge measurement technique that is applied in this TI design to improve the offset drift performance of the system.
C. Measuring the ac-excited bridge with multimeters DMM1 and DMM2. The multimeters provide an accurate bridge voltage which is used as a reference for calculating the error in the ADC measurements.
The calibration and measurement procedure is broken up into four steps: Offset-calibration, bridge measurement for “no load”, gain calibration, and bridge measurement for “max load”. Offset-calibration correction is applied to all subsequent steps. However, gain-calibration is only applied to the bridge measurement for “max load” (full-scale output) because gain-error is insignificant for the “no load” (0V input) case.

The offset-calibration procedure was performed as follows:
1. Set the thermostream to a standard room temperature (25°C). The system will be calibrated at this temperature.
2. Open switches SW1 and SW4 so that the bridge output voltage is nearly 0 V.
3. Measure the initial ADC’s reference voltage (using the ADC). See Appendix B.1 for this software procedure. Store the result as VREF_INIT_ADC. (This value is only used to convert the ADC codes to voltages. In practice, the reference voltage does not need to be measured as the ADC code can be converted to a percentage of the full-scale load.)
4. Measure the excitation voltage of the bridge with the DMM2. Store the result as VREF_INIT_DMM.
5. Measure the initial offset voltage of the bridge in three different ways:
a. Measure the (average) dc-excited bridge output offset voltage with the ADC. Take the average of 16 samples (it may help to convert the samples from hexadecimal to decimal, making sure the sign is correct) to reduce the noise in the offset measurement result. Convert the average code to a voltage (using VREF_INIT_ADC) as shown in Equation C-1. Store the result as OFFSETDC

- | ⋅ = | ⋅ | GAIN

2
2
CODE OFFSET (V) | _ | _
DC | 32
VREF INIT ADC | ( C-1 )

(NOTE: “CODE” is the ADC’s output code and “GAIN” is 32 V/V. Equation C-1 may be used generally to convert ADS1262 output codes to their voltage representations).
b. Measure the (average) ac-excited bridge output offset voltages with the ADC. Take a total of 32 samples (16 samples for each excitation polarity). Average the 16 samples taken with each excitation polarity. Convert these average codes to voltages (using VREF_INIT_ADC) then plug these averages into Equation 3 to calculate the average ac-excited bridge offset voltage (subtract these two averages, and then divide by 2). Store the result as
OFFSETAC.

TIDUAC1A-July 2015-Revised February 2019 | Precision Weigh-Scale Reference Design with AC Bridge Excitation | 25
c. Measure the (average) ac-excited bridge output offset voltages with DMM1. Take a measurement for each excitation polarity and store the results as VOS_DMM_P and
VOS_DMM_N.
(“VOS_DMM_P” is the bridge output offset voltage with a positive excitation polarity and “VOS_DMM_N” is the bridge output offset voltage with a negative excitation polarity). While measuring the bridge output, also measure the bridge excitation voltages with DMM2.Take a measurement for each excitation polarity and store the results as
VREF_OS_DMM_P and VREF_OS_DMM_N.
(“VREF_OS_DMM_P” is the bridge output offset voltage for a positive excitation polarity, “VREF_OS_DMM_N” is the bridge output offset voltage for a negative excitation polarity).
To compute the offset voltage coefficient of the DMM measurements normalize and average the DMM voltage readings to simulate a ratiometric measurement, as shown in Equations C-2 through C-4. Store the result as OFFSETDMM.

= | ⋅ OS_DMM_P

REF_OS_DMM_P

REF_INIT_DMM
OS_DMM_P_NORM | V
V

V
V | ( C-2 )

= | ⋅ OS_DMM_N

REF_OS_DMM_N

REF_INIT_DMM
OS_DMM_N_NORM | V
V

V
V | ( C-3 )

2

VOS_DMM_P_NORM − VOS_DMM_N_NORM OFFSETDMM = | ( C-4 )

Next the bridge offset drift was measured across temperature for the “no load” condition:
6. Change the temperature setting of the thermostream. Wait 5 minutes (“soaking time”) for the system temperature to stabilize to the ambient temperature.
7. Measure the output voltage of the bridge using the three measurement methods.
a. Measure the (average) dc-excited bridge output offset voltage with the ADC. Take the average of 16 samples and convert the average code to a voltage (using VREF_INIT_ADC). Subtract OFFSETDC from this value and store the result as VOS_DC_<X>°C (where “<x>” is the current ambient temperature).
b. Measure the (average) ac-excited bridge output offset voltage with the ADC. Take 32 samples (16 samples for each excitation polarity). Calculate the average values for each polarity and convert these values to voltages (using VREF_INIT_ADC). Calculate a single average voltage using Equation 3. Subtract OFFSETDC from this value and store the result as VOS_AC_<X>°C (where “<x>” is the current ambient temperature).

26 | Precision Weigh-Scale Reference Design with AC Bridge Excitation | TIDUAC1A-July 2015-Revised February 2019
c. Measure the (average) ac-excited bridge output offset voltages with DMM1. Take a measurement for each excitation polarity and store the results as VOS_DMM_<X>°C_P and
VOS_DMM_<X>°C_N.
(“VOS_DMM_<X>°C_P” is the bridge output offset voltage with a positive excitation polarity and “VOS_DMM_<X>°C_N” is the bridge output offset voltage with a negative excitation polarity). While measuring the bridge output, also measure the bridge excitation voltages with DMM2.Take a measurement for each excitation polarity and store the results as
VREF_OS_DMM_ <X>°C_P and VREF_OS_DMM_ <X>°C_N.
(“VREF_OS_DMM_<X>°C_P” is the bridge output offset voltage for a positive excitation polarity, “VREF_OS_DMM_<X>°C_N” is the bridge output offset voltage for a negative excitation polarity, and “<x>” is the current ambient temperature).
To compute the ideal voltage (as should have been seen by the ADC) normalize, average, and subtract the offset from the DMM voltage readings then store the result as VOS_DMM_<X>°C, as shown in Equations C-5 through C-7.

= | ⋅ | < >

< >

< > | OS_DMM_ X °C_P
REF_DMM_ X °C_P

REF_INIT_DMM
OS_DMM_ X °C_P_NORM | V
V

V
V | ( C-5 )

= | ⋅ | < >

< >

< > | OS_DMM_ X °C_N
REF_DMM_ X °C_N

REF_INIT_DMM
OS_DMM_ X °C_N_NORM | V
V

V
V | ( C-6 )

### − OFFSETDMM

− = | < > | < >
< > | 2
| V | V
V | OS_DMM_ X °C_P_NORM | OS_DMM_ X °C_N_NORM
OS_DMM_ X °C | ( C-7 )
8. Repeat steps 6 and 7 for all desired temperature settings. Compare all VOS_DC_<X>°C and VOS_AC_<X>°C to VOS_DMM_<X>°C to see if the ac bridge excitation improved the offset drift performance for the “no load” condition.

Next the gain-calibration procedure was performed as follows:
9. Set the thermostream to a standard room temperature (25°C). The system will be calibrated at this temperature. (Allow time for the system to stabilize back to room temperature if needed.)
10. Close switches SW1 and SW4. (The full-scale bridge output voltage is about 10 mV).
11. Measure the full-scale output voltage of the bridge in three different ways:
a. Measure the dc-excited full-scale bridge output voltage with the ADC. Take the average of 16 samples to reduce the noise in the offset measurement result. Convert the average code to a voltage (using VREF_INIT_ADC) and subtract OFFSETDC. Finally, divide 10 mV by this result and store as GAINDC.
b. Measure the (average) ac-excited full-scale bridge output voltages with the ADC. Take a total of 32 samples (16 samples for each excitation polarity). Average the 16 samples taken with each excitation polarity. Convert these average codes to voltages (using VREF_INIT_ADC) then substitute these two average measurements into Equation 3, to get a single averaged result. Finally, divide 10 mV by this result and store as GAINAC.

TIDUAC1A-July 2015-Revised February 2019 | Precision Weigh-Scale Reference Design with AC Bridge Excitation | 27
c. Measure the ac-excited full-scale bridge output voltages with DMM1. Take a
measurement for each excitation polarity and store the results as VFS_DMM_P and VFS_DMM_N. (“VFS_DMM_P” is the full-scale bridge output voltage with a positive excitation polarity and “VFS_DMM_N” is the full-scale bridge output voltage with a negative excitation polarity). While measuring the bridge output, also measure the bridge excitation voltages with DMM2.Take a measurement for each excitation polarity and store the results as VREF_FS_P
and VREF_FS_N.
(“VREF_FS_DMM_P” is the full-scale bridge output voltage with a positive excitation polarity and “VREF_FS_DMM_N” is the full-scale bridge output voltage with a negative excitation polarity). To compute the gain calibration coefficient for the DMM measurements, normalize, average, and subtract the (averaged) ac-excited bridge offset voltage from the DMM voltage readings. Then, divide 10 mV by this result and store this value as GAINDMM, as shown in Equations C-8 through C-10.

= | ⋅ FS_DMM_P

REF_FS_DMM_P

REF_INIT_DMM
FS_DMM_P_NORM | V
V

V
V | ( C-8 )

= | ⋅ FS_DMM_N

REF_FS_DMM_N

REF_INIT_DMM
FS_DMM_N_NORM | V
V

V
V | ( C-9 )

- − − =

DMM

DMM

### OFFSET

### mV GAIN

2

V | V

10

FS_DMM_P_NORM | FS_DMM_N_NORM | ( C-10 )

Finally, the bridge offset drift was measured across temperature for the “max load” condition:
12. Change the temperature setting of the thermostream. Wait 5 minutes (“soaking time”) for the system temperature to stabilize to the ambient temperature.
13. Measure the output voltage of the bridge using the three measurement methods.
a. Measure the dc-excited full-scale bridge output voltage with the ADC. Take 16 samples and convert the average result to a voltage (using VREF_INIT_ADC). Subtract OFFSETDC from this value, multiply by GAINDC, and store the result as VFS_DC_<X>°C (where “<x>” is the current ambient temperature).
b. Measure the (average) ac-excited full-scale bridge output voltage with the ADC. Take 32 samples (16 samples for each excitation polarity). Average the 16 samples taken with each excitation polarity. Convert the averages to voltages (using VREF_INIT_ADC). Calculate a single average voltage using Equation 3. Subtract OFFSETDC from this value, multiply by GAINAC, and store the result as VFS_AC_<X>°C (where “<x>” is the current ambient temperature).

28 | Precision Weigh-Scale Reference Design with AC Bridge Excitation | TIDUAC1A-July 2015-Revised February 2019
c. Measure the ac-excited full-scale bridge output voltages with DMM1. Take a
measurement for each excitation polarity and store the results as VFS_DMM_ <X>°C_P and
VFS_DMM_ <X>°C_N.
(“VFS_DMM_ <X>°C_P” is the full-scale bridge output voltage for a positive excitation polarity and “VFS_DMM_ <X>°C_N” is the full-scale bridge output voltage for a negative excitation polarity, and “<x>” is the current ambient temperature).
While measuring the bridge output, also measure the bridge excitation voltages with DMM2.Take a measurement for each excitation polarity and store the results as
VREF_FS_DMM_ <X>°C_P and VREF_FS_DMM_ <X>°C_N.
(“VREF_FS_DMM_ <X>°C_P” is the bridge output offset voltage with a positive excitation polarity, “VREF_FS_DMM_ <X>°C_N” is the bridge output offset voltage with a negative excitation polarity, and “<x>” is the current ambient temperature).
To compute the ideal voltage (as should have been seen by the ADC) normalize, average, subtract the offset, and multiply by the gain calibration coefficient before storing the result as VFS_DMM_<X>°C, as shown in Equations C-11 through C-13.

= | ⋅ | < >

< >

< > | FS_DMM_ X °C_P
REF_FS_DMM_ X °C_P

REF_INIT_DMM
FS_DMM_ X °C_P_NORM | V
V

V
V | ( C-11 )

= | ⋅ | < >

< >

< > | FS_DMM_ X °C_N
REF_FS_DMM_ X °C_N

REF_INIT_DMM
FS_DMM_ X °C_N_NORM | V
V

V
V | ( C-12 )
OFFSETDMM | GAIN DMM ⋅
- | − − = | < > | < >
< > | 2
V | V
V | FS_DMM_ X °C_P_NORM | FS_DMM_ X °C_N_NORM
FS_DMM_ X °C | ( C-13 )
14. Repeat steps 12 and 13 for all desired temperature settings. Compare all VFS_DC_<X>°C and VFS_AC_<X>°C to VFS_DMM_<X>°C to see if ac bridge excitation improved the offset drift performance for the “max load” condition.

IMPORTANT NOTICE AND DISCLAIMER

TI PROVIDES TECHNICAL AND RELIABILITY DATA (INCLUDING DATASHEETS), DESIGN RESOURCES (INCLUDING REFERENCE DESIGNS), APPLICATION OR OTHER DESIGN ADVICE, WEB TOOLS, SAFETY INFORMATION, AND OTHER RESOURCES “AS IS” AND WITH ALL FAULTS, AND DISCLAIMS ALL WARRANTIES, EXPRESS AND IMPLIED, INCLUDING WITHOUT LIMITATION ANY IMPLIED WARRANTIES OF MERCHANTABILITY, FITNESS FOR A PARTICULAR PURPOSE OR NON-INFRINGEMENT OF THIRD PARTY INTELLECTUAL PROPERTY RIGHTS.
These resources are intended for skilled developers designing with TI products. You are solely responsible for (1) selecting the appropriate TI products for your application, (2) designing, validating and testing your application, and (3) ensuring your application meets applicable standards, and any other safety, security, or other requirements. These resources are subject to change without notice. TI grants you permission to use these resources only for development of an application that uses the TI products described in the resource. Other reproduction and display of these resources is prohibited. No license is granted to any other TI intellectual property right or to any third party intellectual property right. TI disclaims responsibility for, and you will fully indemnify TI and its representatives against, any claims, damages, costs, losses, and liabilities arising out of your use of these resources.
TI’s products are provided subject to TI’s Terms of Sale (www.ti.com/legal/termsofsale.html) or other applicable terms available either on ti.com or provided in conjunction with such TI products. TI’s provision of these resources does not expand or otherwise alter TI’s applicable warranties or warranty disclaimers for TI products.

Mailing Address: Texas Instruments, Post Office Box 655303, Dallas, Texas 75265 Copyright © 2019, Texas Instruments Incorporated

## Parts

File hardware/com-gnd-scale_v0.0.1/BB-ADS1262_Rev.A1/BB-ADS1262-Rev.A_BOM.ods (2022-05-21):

Designation | Quantity | Designator | Package
HN1x13 | 1 | CON1 | HN1x13
СЪЕДИНИТЕЛ BH10S (B-D-02x5-LF) | 1 | CON3 | UEXTF
SMD ИС ADS1262IPW | 1 | U1 | TSSOP28-PW
HN1x10 | 1 | CON2 | HN1x10
SMD КОНД 0603 100 NF X7R 50VDC 10% | 3 | C3,C1,C2 | C_0603_5MIL_DWS
SMD КОНД 0603 1 UF 10V X5R | 4 | C4,C6,C21,C22 | C_0603_5MIL_DWS
SMD КОНД 0603 4.7 NF X7R 50VDC 10% | 1 | C5 | C_0603_5MIL_DWS
SMD РЕЗ 0603 1 K 5% | 1 | R2 | R_0603_5MIL_DWS
SMD КОНД 0603 22 UF 6.3V | 1 | C18, C19 | C_0603_5MIL_DWS
SMD ДИОД 1N5819 (S4 SOD-123) | 2 | D1,D3 | SOD-123_KA
FB0603 | 1 | FB1 | L_0603_5MIL_DWS
SMD ИНД CL10 UH SD73 | 1 | L1 | SD73
SMD РЕЗ 0603 9.1 K 1% | 1 | R17 | R_0603_5MIL_DWS
SMD РЕЗ 0603 1.05 K 1% | 2 | R18,R28 | R_0603_5MIL_DWS
SMD РЕЗ 0603 5.6 K 1% | 1 | R27 | R_0603_5MIL_DWS
SMD ИС MT3608 2-24V 2A | 1 | U2 | SOT23-6
SMD ИС AP2127K-ADJ (SOT23-5) | 1 | U3 | SOT-23-5

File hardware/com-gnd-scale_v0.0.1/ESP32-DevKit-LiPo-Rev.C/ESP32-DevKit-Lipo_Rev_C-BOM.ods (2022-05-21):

Quantity | Designation | Package | Designator
1 | 220R/R0402 | R0402 | R10
4 | 2.2k/R0402 | R0402 | R3,R4,R8,R9
4 | 10k/R0402 | R0402 | R1,R6,R13,R17
1 | 49.9k/1%/R0402 | R0402 | R12
2 | 220k/R0402 | R0402 | R11,R15
3 | 470k/R0402 | R0402 | R2,R5,R16
1 | 2.2uH/1.5A/DCR=72mR/20%/ 3.00x3.00x1.50mm/ CD32(NR3015T2R2M) | CD32 | L1
2 | 27pF/50V/5%/C0G/C0402 | C0402 | C2,C3
2 | 100nF/10V/10%/X7R/C0402 | C0402 | C5,C9
1 | 1uF/10V/10%/X5R/C0603 | C0603 | C8
4 | 22uF/6.3V/20%/X5R/C0603 | C0603 | C4,C1,C6,C7
1 | LED/YELLOW/0603 | LED_0603 | CHARGING1
1 | BAT54C(SOT23-3) | SOT23-3 | D3
4 | 1N5819S4/SOD123 | SOD-123 | D1,D2,D4,D5
2 | BC817-40(SOT23) | SOT23 | Q2,Q3
1 | WPM2015-3/TR | SOT23 | FET1
1 | BL4054B-42TPRN(SOT23-5) | SOT-23-5 | U1
1 | CH340T(SSOP20W) | SSOP-20W | U2
1 | SY8089AAAC(SOT23-5) | SOT-23-5 | U3
1 | Q12MHz/20pF/10ppm/4P/3.2x2.5mm | TSX-3.2x2.5mm | Q1
1 | MISB-SWMM-5B-LF(USB_MICRO) | MISB-SWMM-5B_LF | USB-UART1
1 | IT-1185AU2-160G-G-TR | IT1185AU2 | RST1
1 | DW02S | DW02S | BAT1
2 | HN1x19 | HN1x19 | EXT1,EXT2
1 | ESP32-WROOM-32D-4MB | ESP32-MODULE_Universal | U5
3 | Opened | SJ | BAT_PWR_E1, BAT_SENS_E1, PWR_SENS_E1
1 | NA/R0402 | R0402 | R7

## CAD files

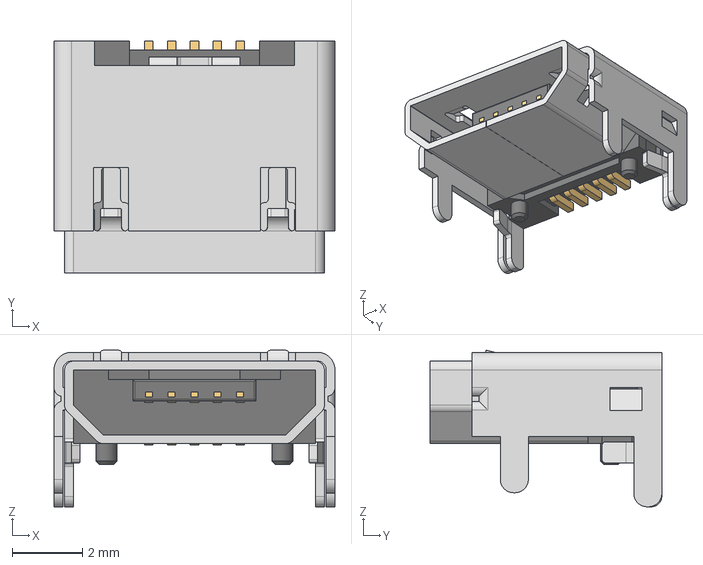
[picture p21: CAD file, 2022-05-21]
hardware/com-gnd-scale_v0.0.1/ESP32-DevKit-LiPo-Rev.C/3d/usb_micro_4p.stp
8.00 x 6.60 x 4.46 mm

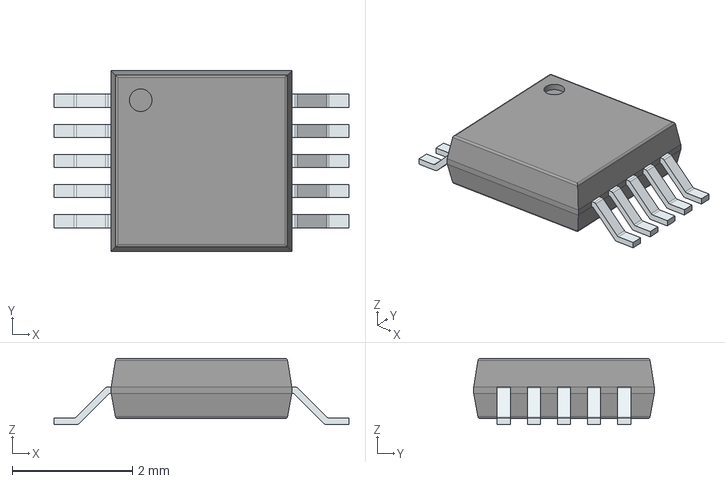
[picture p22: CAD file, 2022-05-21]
hardware/LIB_DG2733EDQ-T1-GE3/DG2733EDQ-T1-GE3/3D/DG2733EDQ-T1-GE3.stp
4.90 x 3.00 x 1.10 mm
PinsArrayLR

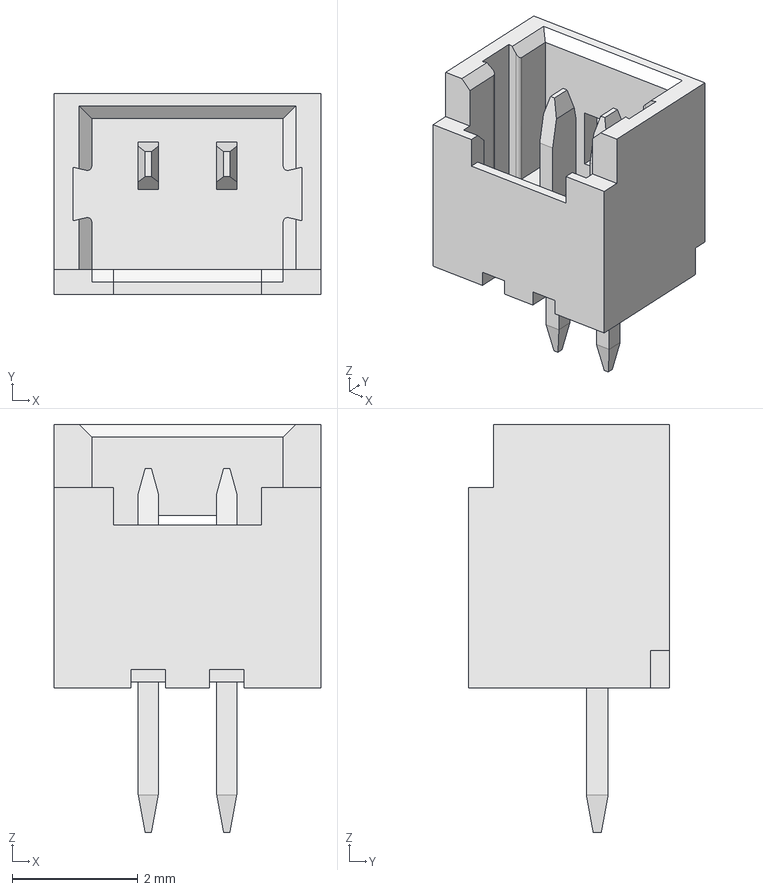
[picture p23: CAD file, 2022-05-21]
hardware/com-gnd-scale_v0.0.1/ESP32-DevKit-LiPo-Rev.C/3d/Molex_PicoBlade_530470210.step
4.25 x 3.20 x 6.50 mm

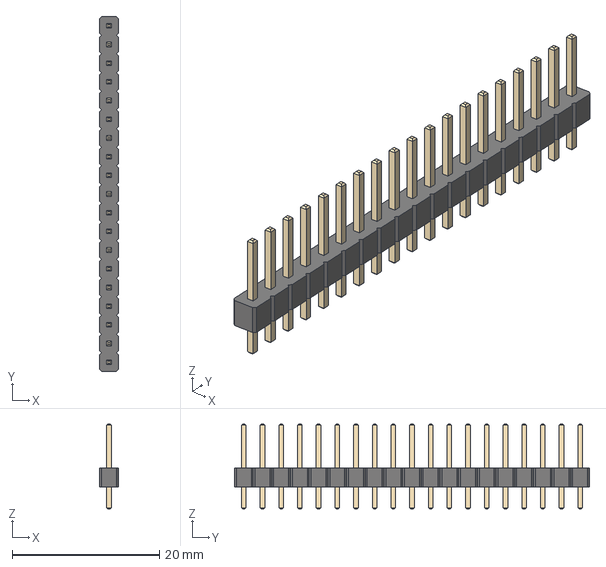
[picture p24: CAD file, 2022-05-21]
hardware/com-gnd-scale_v0.0.1/ESP32-DevKit-LiPo-Rev.C/3d/HN1x19-PinHeader_1x19_P2.54mm_Vertical.step
2.54 x 48.3 x 11.5 mm

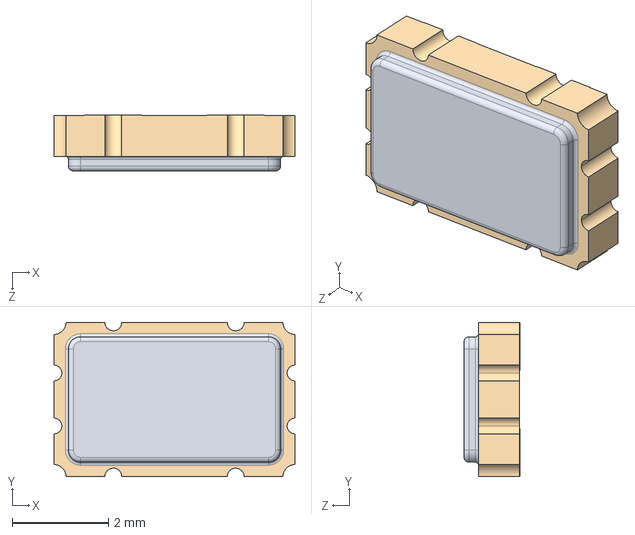
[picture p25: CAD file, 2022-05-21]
hardware/com-gnd-scale_v0.0.1/ESP32-DevKit-LiPo-Rev.C/3d/QSG5032.step
5.00 x 3.20 x 1.16 mm

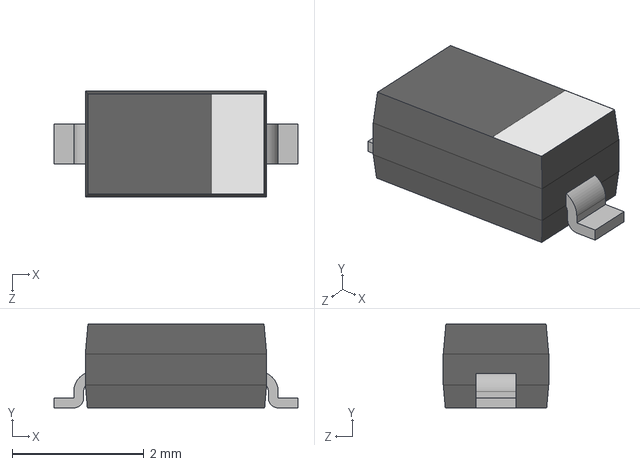
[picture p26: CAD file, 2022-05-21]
hardware/com-gnd-scale_v0.0.1/ESP32-DevKit-LiPo-Rev.C/3d/SOD123.step
3.70 x 1.27 x 1.60 mm

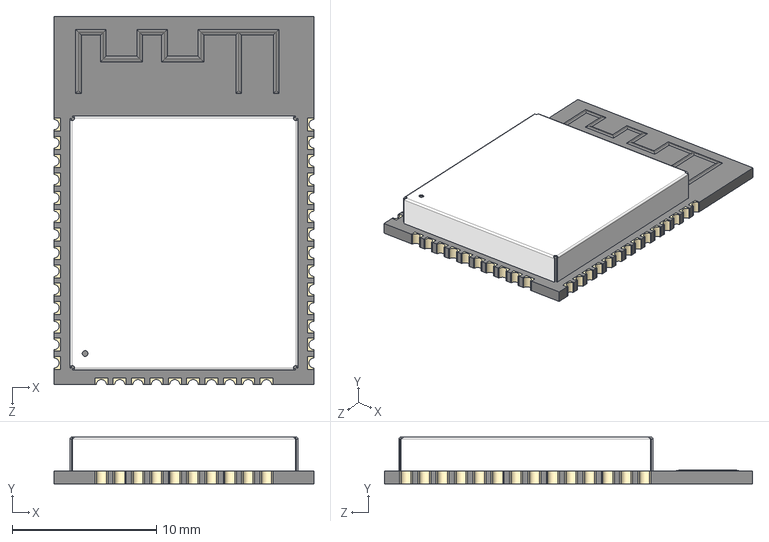
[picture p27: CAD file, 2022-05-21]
hardware/com-gnd-scale_v0.0.1/ESP32-DevKit-LiPo-Rev.C/3d/ESP32-WROOM-32D-56544.STEP
18.0 x 3.25 x 25.5 mm

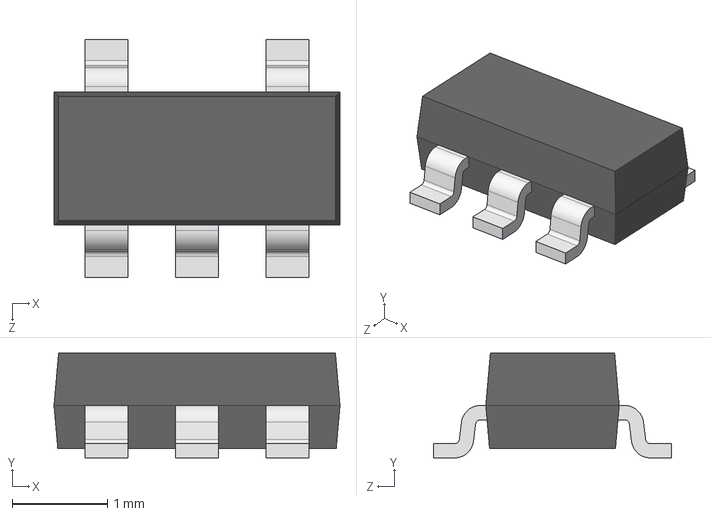
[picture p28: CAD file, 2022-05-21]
hardware/com-gnd-scale_v0.0.1/ESP32-DevKit-LiPo-Rev.C/3d/SOT-23-5.step
3.00 x 1.10 x 2.50 mm

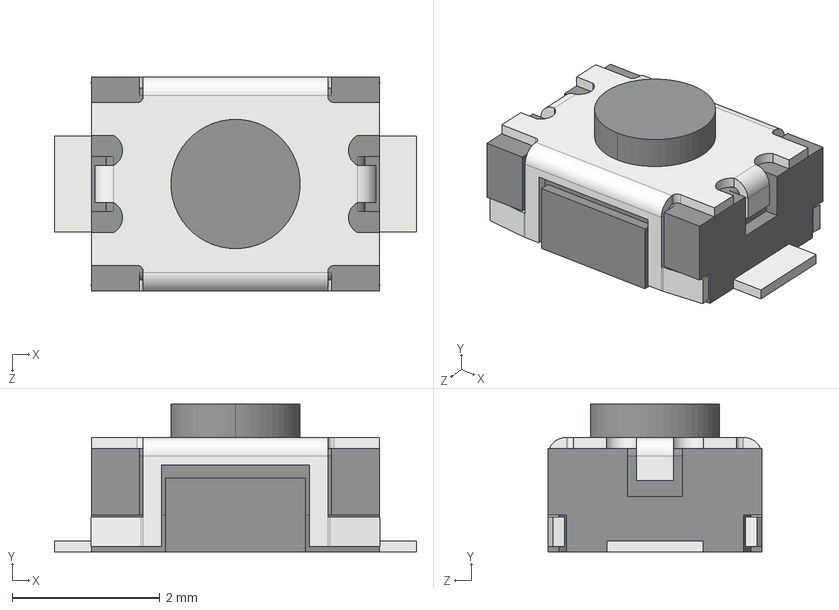
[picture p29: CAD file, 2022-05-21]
hardware/com-gnd-scale_v0.0.1/ESP32-DevKit-LiPo-Rev.C/3d/it1185.step
4.90 x 2.00 x 2.90 mm

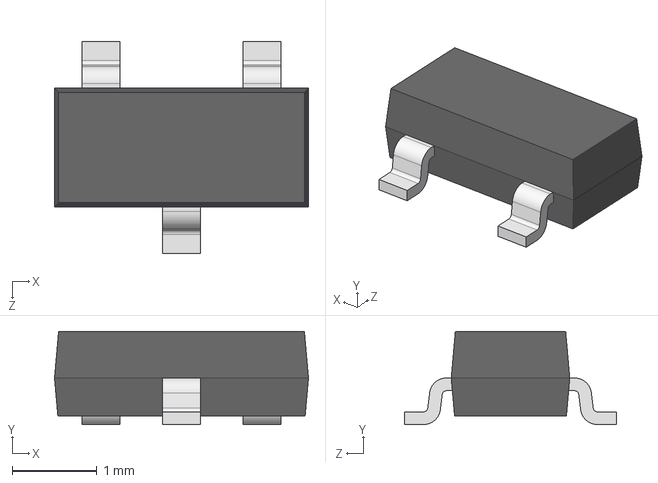
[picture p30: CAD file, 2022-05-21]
hardware/com-gnd-scale_v0.0.1/ESP32-DevKit-LiPo-Rev.C/3d/SOT-23.step
3.00 x 1.10 x 2.50 mm

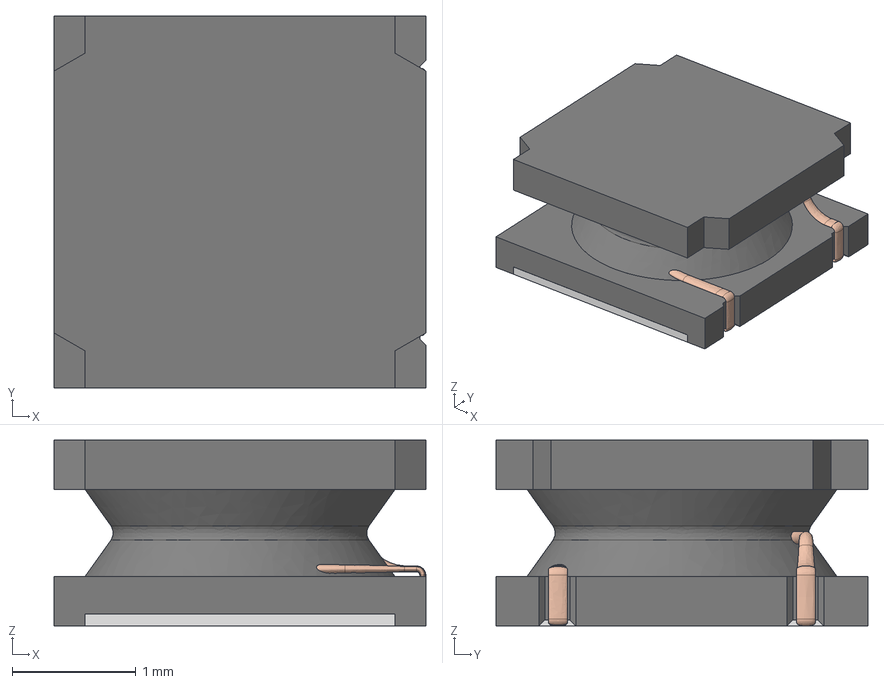
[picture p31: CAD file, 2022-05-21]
hardware/com-gnd-scale_v0.0.1/ESP32-DevKit-LiPo-Rev.C/3d/L-CD32_shielded.step
3.00 x 3.00 x 1.50 mm

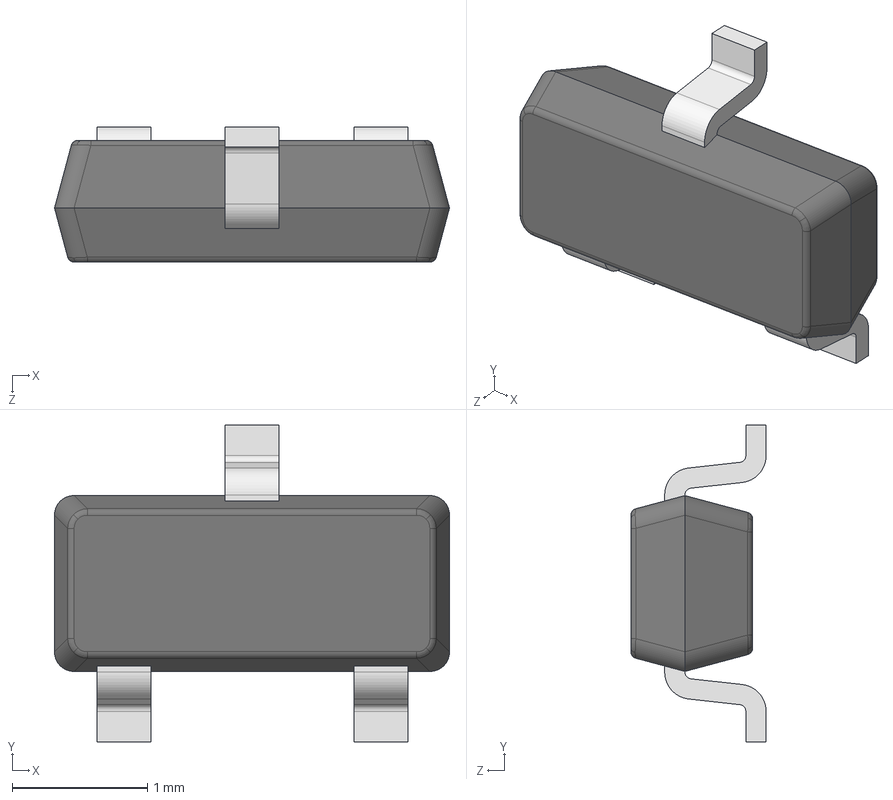
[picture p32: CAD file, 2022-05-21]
hardware/com-gnd-scale_v0.0.1/ESP32-DevKit-LiPo-Rev.C/3d/BAT54.step
2.92 x 2.34 x 1.00 mm

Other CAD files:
hardware/LIB_DG2733EDQ-T1-GE3/DG2733EDQ-T1-GE3/3D/DG2733EDQ-T1-GE3.stl
hardware/LIB_DG2733EDQ-T1-GE3/DG2733EDQ-T1-GE3/Allegro/sop50p490x110-10n.psm
hardware/LIB_DG2733EDQ-T1-GE3/DG2733EDQ-T1-GE3/DEHDL/dg2733edq_t1_ge3/chips/chips.prt

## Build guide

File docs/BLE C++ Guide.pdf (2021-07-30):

January 1st 2018

Bluetooth BLE
Using the low level ESP-IDF functions to build a BLE solution is considered difficult. There are a lot of concepts and there is a lot of state to be considered plus inbound events needing to be handled. This feels like an ideal candidate for a higher level class encapsulation to simplify our tasks. To that end, we have created a set of C++ classes that provide all the needed BLE capabilities with an easier model of usage.
When using these classes, we must use make menuconfig to configure our ESP-IDF environment. First, we need to ensure that Bluetooth is enabled. Start make menuconfig and navigate to Component config and select Bluetooth:

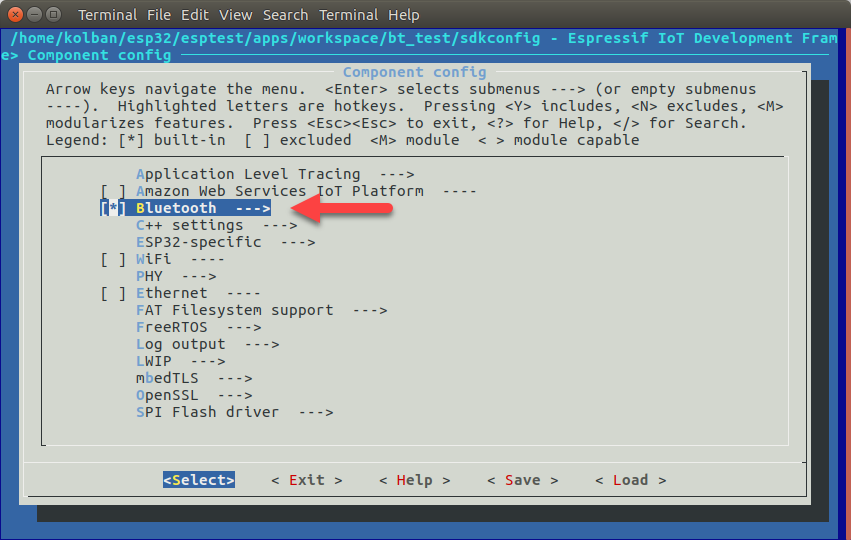
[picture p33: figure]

Next drill into the Bluetooth entry and ensure "Bluedroid Bluetooth stack enabled" is selected:

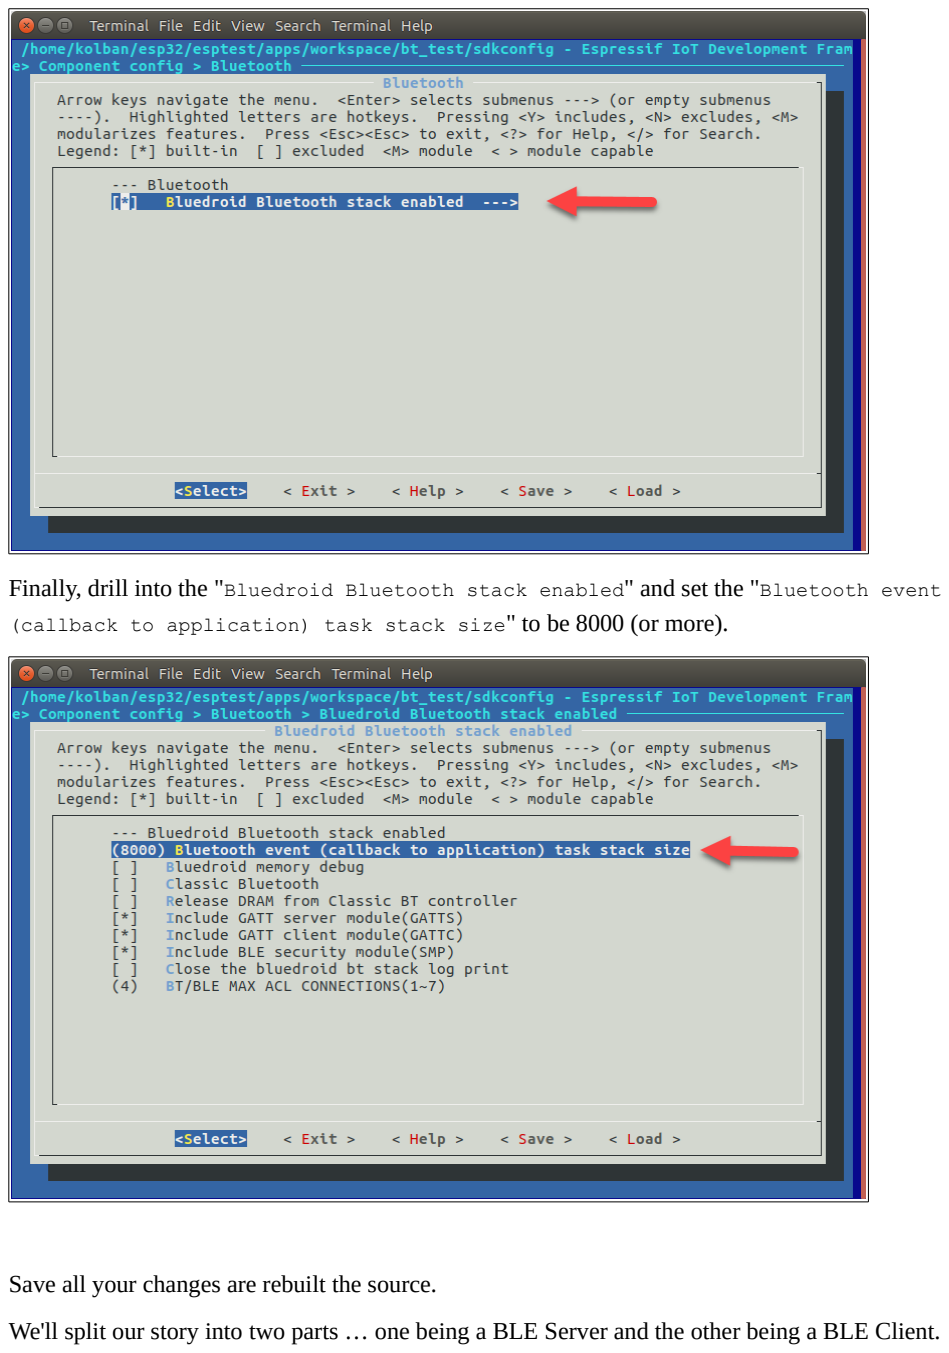
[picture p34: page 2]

Finally, drill into the "Bluedroid Bluetooth stack enabled" and set the "Bluetooth event (callback to application) task stack size" to be 8000 (or more).

Save all your changes are rebuilt the source.
We'll split our story into two parts … one being a BLE Server and the other being a BLE Client.

A BLE Server
A BLE Server is also known as a BLE Peripheral. It is likely that this is how you will most commonly use the ESP32. With a BLE Server, you will expose one or more services where each service has one or more characteristics and each characteristic may have zero or more descriptors. I think we'll agree that is quite a lot going on.

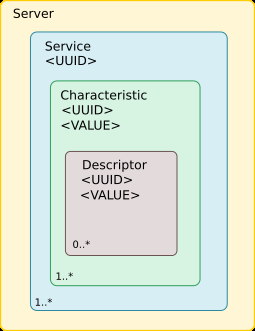
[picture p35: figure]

In our C++ model, we create the concept of classes that represent these items.
- BLEServer – Models a server.
- BLEService – Models a service. Owned by a BLEServer.
- BLECharacteristic – Models a characteristic. Owned by a BLEService.
- BLEDescriptor – Models a descriptor. Owned by a BLECharacteristic.

And also:
- BLEAdvertising – Models advertising. Owned by a BLEServer to let others know of our existence.

At a high level, the pseudo code of a minimal BLE server becomes:

// Initialize the BLE environment BLEDevice::init("ServerName");

// Create the server
BLEServer* pServer = BLEDevice::createServer();

// Create the service
BLEService* pService = pServer->createService(ServiceUUID);

// Create the characteristic
BLECharacteristic* pCharacteristic = pService->createCharacteristic(CharacteristicUUID, properties);

// Set the characteristic value
pCharacteristic->setValue("Hello world");

// Start the service
pService->start();

Hopefully you see how this fits together … we create the server, we create the service, create a characteristic upon the service, set a value for the characteristic and then ask the service to start responding to incoming requests.
If you are familiar with the ESP32 BLE APIs supplied by ESP-IDF, you may notice what is missing … all the complexity and glue code necessary for event handling and processing of BLE requests. All of this is handled for you by the implementation of the classes. This means that you can focus on your intent/usage of BLE while keeping your plumbing to a minimum.
The goal of these classes is to efficiently process BLE workflow while encapsulating the plumbing so you don't need to worry about it … but within is the danger that the implementation will restrict you from some tasks by hiding functions that you might otherwise have needed for your own project. Thankfully, this has not been seen to be the case. The classes expose simple high level APIs for the 95% of common practices while at the same time providing methods that can be called to tweak and tailor the operations for the rarer cases. Hopefully you won't need those often but, if and when you do, they are there for you.
When a BLE Server is running, what must happen next is that peer devices (clients) must be able to locate it. This is made possible through the notion of advertising. The BLE Server can broadcast its existence along with sufficient information to allow a client to know what services it can provide. Once we have started the BLE Server, we can ask it for an object (BLEAdvertising) that owns the advertisements that the server produces:

BLEAdvertising* pAdvertising = pServer->getAdvertising();
pAdvertising->start();
Once performed, the server can be dynamically found by the clients. Of course a server doesn't need to advertise. If a client should otherwise be informed (or remember) the address of the BLE server, it can request a connection at any time.
As part of the advertisement offered by the BLE device we have the option of telling potential interested parties about the services our device offers. We can advertise one or more services by calling the addServiceUUID() method prior to starting to advertise.

The ESP-IDF provides a built-in structure for common advertisements but there are many more advertisement types than those chosen by Espressif. To support this, we can construct our own advertisement payload and associate that with what the ESP32 advertises. This is achieved through the BLEAdvertisementData class type. We create an instance of this class, populate it with the advertisement payload we wish to distribute and then start advertising.
At a high level:

BLEAdvertising* pAdvertising = pServer->getAdvertising(); BLEAdvertisementData advertisementData;
// set the properties of the advertisement data
// See the setter methods of the BLEAdvertisementData class pAdvertising->setAdvertisementData(advertisementData); pAdvertising->start();

A core concept of BLE is the notion of the characteristic. Think of this as a stateful record that has an identity and a value. A peer device (if permitted) can read the value of the characteristic or set a new value. Remember, it the BLE characteristic that owns the existence of the value so that it may be served up or changed upon request. This is the core notion of BLE. The value read from the characteristic provides information. For example, if the characteristic represents your heart-rate measured from a sensor, then a remote client can retrieve your current heart rate by reading the current characteristic value. In this case, a remote client will not be setting the value, instead the value will be changed internally by the server either each time a read request by a client is made or when a new sensor reading is taken. Alternatively, the characteristic maintained in the BLE Server may represent the state of something that can be activated or changed. As another example, imagine that the characteristic represents the state of your car door's lock. You can read the characteristic to determine that your door is locked when you leave or, conversely, you can set the characteristic's value to an unlocked state which would result in the server mechanically unlocking the door.
To model these notions in our C++ classes, we leverage the notion that a C++ class can be sub-classed to be more specialized. A class called BLECharacteristicCallbacks provides two methods that can be over-riden:
- onRead(BLECharacteristic* pCharacteristic) – Called when a read request arrives from a client. A new value for the characteristic can be set before return from the function and will be used as the value received by the client.
- onWrite(BLECharacteristic* pCharacteristic) – Called when a client initiated write request arrives. The new value has been set in the characteristic already and your own code logic can read the value and perform some action.

To utilize, we can then override these functions in our own C++ class that sub-classes the one provided:

class MyCallback: public BLECharateristicCallback {
void onRead(BLECharacteristic* pCharacteristic) {
// Do something before the read completes.

}

void onWrite(BLECharacteristic* pCharacteristic) { // Do something because a new value was written. }
}

To use this technique, we inform our BLECharacteristic about a callback handler. For example:

pCharacteristic->setCallbacks(new MyCallback());

Here is an example that sends the time since startup each time a client requests the value:

class MyCallbackHandler: public BLECharacteristicCallbacks {
void onRead(BLECharacteristic* pCharacteristic) {
struct timeval tv;
gettimeofday(&tv, nullptr);
std::ostringstream os;
os << "Time: " << tv.tv_sec; pCharacteristic->setValue(os.str()); }
};

Similar to the characteristic callbacks, we also have server callbacks. These inform your code about client connection and disconnection events. These are sub-classed from the BLEServerCallbacks class which has virtual methods for:
- onConnect(BLEServer* pServer) – Called when a connection occurs.
- onDisconnect(BLEServer* pServer) – Called when a disconnection occurs.

These could be used to enable or disable sensor readings. For example, if we have no clients connected then there is no need to spend energy sampling a value if there is no-one there to read it. However, when a client connects, we can detect that and start reading from the sensor at that point until a subsequent disconnection indication is detected.
Another consideration for our BLE Server is the idea that we might want to "push" data to the peer when something interesting happens. Up until now we have considered the idea that the server can receive read requests to get the current value or can receive write requests to set the current value. There is one more operation that we are interested in that is invoked on the server side by the server and asynchronously to the client. That operation is called "notify". It is used to signal (or notify) to the client that the characteristic's value has changed. The client will receive an indication event to let it know that the change has occurred.
On the server, we can cause an indication to occur by invoking:

pCharacteristic->notify();

The current value of the characteristic will be the value transmitted to the peer. We might pair this call with a previous request to set a new value:

pCharacteristic->setValue("HighTemp");
pCharacteristic->notify();
A similar function to notify() is called indicate(). The distinction between them is that an indicate() receives a confirmation while a notify() does not receive a confirmation.

Associated with the idea of indications/notifications, is the architected BLE Descriptor called "Client Characteristic Configuration" (https://www.bluetooth.com/specifications/gatt/viewer) which has UUID 0x2902. This contains (among other things) two distinct bit fields that can be on or off. One bit field governs Notifications while the other governs Indications. If the corresponding bit is on, then the server can/may send the corresponding push. For example if the Notifications bit is on, then the server can/may send notifications. The primary purpose of the descriptor is to allow a partner (a client) to request that the server actually send notifications or indications. Here is an example.
Imagine that we have a BLE Server that can publish notifications when data changes. Now imagine that a BLE Client connects but is actually not interested in receiving these. If the BLE Server executes a notification push and sends the data, that will be wasted effort/energy as the client doesn't want or can't use the information. What we really want is that the client should inform the server that if it wants to push new data then it either should or shouldn't. And that is where this descriptor comes into play. If the descriptor is present on a characteristic then then client can remotely change the bit flag to enable or disable notifications and indications. Since the descriptor flag is stored locally within the server, the server is at liberty to examine the flag before performing a radio transmission. What this means is that the client/peer can toggle on or off its desire to receive notifications and the server should honor those requests.
The BLE specification constrains the maximum amount of data that can be sent through a notification or indication to be 20 bytes or less. Take this into account in your designs. If the value of a characteristic is greater than this amount, then only the first 20 bytes of the data will be transmitted.
It is likely that your own BLE server application is going to expose its own set of characteristics. Through a characteristic you can set and get the value as a binary piece of storage, however this may be too low level for you. An alternative is to utilize the features of the C++ language and model your own specialized characteristic as a sub class of BLECharacteristic. This could then encapsulate the lower level value's getter and setter with your own customized version.
For example, if your characteristic represented a temperature, you could create:

class MyTemperatureCharacteristic: public BLECharacteristic { MyTemperature(): BleCharacteristic(BLEUUID(MYUUID)) { setTemperature(0.0);
}

void setTemperature(double temp) {
setValue(&temp, sizeof temp); }

double getTemperature() {

return *(double*)getValue(); }
}

A BLE Client
Now we will turn our attention to the second half of our story, namely that of being a client. In this story, our ESP32 doesn't host services but instead wishes to be a consumer of services hosted elsewhere. The story can further be broken down into two sub-stories … namely scanning and interaction.
If we assume that our ESP32 starts up and wishes to be a client of a remote BLE server then it has to connect to that server. In order to connect to the server, we need to know the address of the target server. An address is a 6 byte value commonly written in the form

nn:nn:nn:nn:nn:nn
While in principle this can be hard-coded into your application or manually entered through some other interaction story, this is not the common practice. Instead, we perform a procedure known as a scan. Scanning is the idea that we actively listen on the BLE radio frequencies for servers which are advertising their existence. As an analogy, imagine we enter a dark room and we have no idea who is in there with us. We take off our ear-muffs (yes, for some reason we entered a dark room with no light at all wearing ear-muffs … but then, this is just an analogy) and we start hearing voices. We hear "Hi this is Bob, I can make toast" and "Hi this is Susan, I can tell you what temperature it is" and we also hear "Hi this is Brian, ask me what I can do". In this analogy, Bob, Susan and Brian are the addresses of the BLE devices. Each of them are continually saying out loud that they exist and, in some cases, what they can do for us.
When we perform a BLE scan, we receive small sized records of data that always contain the address of the advertiser and sometimes additional information such as the services they provide or other descriptive items. This information arrives at us passively. All we need do is listen and we learn. Should we need to learn more about the devices, we can connect to them (even the ones that told us little) and explicitly ask them for more details of what they can do.
That is the principle of scanning. In our C++ BLE story, we have modeled this through the C++ class called BLEScan. We get an instance of this class by asking the BLE device for it using:

BLEScan* pMyScan = BLEDevice::getScan();

The object returned to us is a singleton. This was chosen because we will only want to be scanning once per ESP32 at any given time.
The BLEScan object, when presented to us, isn't actually yet scanning, to start it scanning we invoke its start() method passing in the duration of how long we would like it to scan for. This is an interval measured in seconds. For example:

pMyScan.start(30); // Scan for 30 seconds

This is a blocking call. It will return after the scan period has elapsed. It returns an object instance of type BLEScanResults that contains the information for each unique device found. If we have an instance of BLEScanResults we can ask it how many results it contains (via a call to getCount()) and we can then retrieve each advertised device (via a call to getDevice(index)).

Since we are scanning, we will want to know as soon as possible about the devices that we find and this is where a callback function comes into play. Before calling start() we can register a callback function that will be invoked for each peer device that was found. An abstract C++ class called BLEAdvertisedDeviceCallbacks works for us here. This has a method on it called onResult() which will be invoked for each unique result found during scanning. Note that we don't pass the same detected device twice; if it wasn't the one you were previously looking for, it still won't be the one you want a short while later. This method is passed in to your callback function as an instance to an object of type BLEAdvertisedDevice that describes the nature of the device that we found.

For example:

class MyCallbacks: public BLEAdvertisedDeviceCallbacks {
void onResult(BLEAdvertisedDevice advertisedDevice) { // Do something with the found device ...
}
}

BLEDevice::init("");
BLESan* pMyScan = BLEDevice::getScan(); pMyScan->setAdvertisedDeviceCallbacks(new MyCallbacks()); pMyScan->start();

What this means is that for every unique device that the scan finds, a call to onResult() will be made which is passed an instance of a BLEAdvertisedDevice which describes that device. Now let us look at what a device may tell us. The only thing that a device will tell us for sure is its BLE address. Beyond that, everything else is optional. The possible attributes that an advertised device may inform us about is large and the following subset have been modeled (so far):
- Appearance
- Manufacturer data
- Name
- RSSI
- Primary service UUID
- Transmit power

Since none of these are mandatory in an advertisement, for any given advertised device we learn about, we can't immediately ask about the value of the property. Instead, we have methods that tell us which properties are present and, if present, then we can ask for its value.
For example, in our processing logic we may code:

if (advertisedDevice.hasServiceUUID()) {
BLEUUID service = advertisedDevice.getServiceUUID(); if (service.equals(BLEUUID((uint16_t)0x1802) {
// we found a useful device …
}
}
(The above is merely an example of the logic that can be employed).
If we wish to end the scan early; presumably because we found the device we wanted, we can call the stop() method of the BLEScan object. A reference to the BLEScan is conveniently available within the
BLEAdvertisedDevice object.

advertisedDevice.getScan()->stop();

From all of this … we end up with the identification of a device that was of interest to us and since we want to be a BLE Client, this will presumably mean the device to which we wish to connect. The key item in the advertisement now becomes the device's address which we can obtain through a call to
getAddress().

Now we can turn our attention to actually connecting to the server.
A BLE Client is modeled as the BLEClient class. We obtain an unconnected instance of this by asking the ESP32 for one:

BLEClient* pMyClient = BLEDevice::createClient();
Next we request a connection to the target device.

pMyClient->connect(address);
… and that's it. The connect() is a blocking call and, on return, we are connected. However, that isn't the end of the story. Just connecting to a peer is usually not enough. Now we want to read and write the values that the remote BLE server is hosting. If we think back to our understanding of the story, the remote server has one or more services and each service has one or more characteristics and it is these characteristics that hold the values. This means that it doesn't make sense to say "I want to read the value of the remote BLE server" … instead we must say "I want to read the value of a named remote characteristic". However, even that is not enough. There may be multiple services on the BLE server each of which have their own characteristic which may be of the same characteristic type and hence not be uniquely identified. Thus we end up with the final concept of "I want to read the value of a named remote characteristic that is owned by a named service". From this notion, we now get to introduce
two more models. Those are the BLERemoteService and BLERemoteCharacteristic.

Once we have connected to a BLE Server, we can request a reference to the BLERemoteService that models a service on that server:

BLERemoteService* pMyRemoteService = pClient->getService(serviceUUID);
and once we have a reference to the service, we can ask that service for a reference to the desired characteristic.

BLERemoteCharacteristic* pMyRemoteCharacteristic = pMyRemoteService->getCharacteristic(characteristicUUID);
and finally … we can work with the values associated with the characteristic:

std::string myValue = pMyRemoteCharacteristic->readValue();
to read the value and …

pMyRemoteCharacteristic->writeValue("abc");
to write a new value. If all that seems like a lot of work … lets put it together in context and see:

// Create the client
BLEClient* pMyClient = BLEDevice::createClient();

// Connect the client to the server
pMyClient->connect(address);

// Get a reference to a specific remote service on the server BLERemoteService* pMyRemoteService = pClient->getService(serviceUUID);

// Get a reference to a specific remote characteristic owned by the service BLERemoteCharacteristic* pMyRemoteCharacteristic = pMyRemoteService->getCharacteristic(characteristicUUID);

// Retrieve the current value of the remote characteristic.
std::string myValue = pMyRemoteCharacteristic->readValue();

… and that's it. Hopefully you see that is pretty elegant (and if not, please contact me and we'll see if we can't improve on it … but come bearing suggestions for what can be improved).
To close, we will look at a BLE Client receiving notifications from the server. Since a server can notify a client at any time, we need a callback mechanism to asynchronously process those events. The BLERemoteCharacteristic object exposes a method called
registerForNotify(callbackHandler). When invoked, we register a callback handler function with the following signature:

void notifyCallback(
BLERemoteCharacteristic* pBLERemoteCharacteristic,
uint8_t* | data,
size_t | length,
bool | isNotify)
This function is invoked when the BLE Server transmits a notification message. The function is called with a reference to the characteristic associated with the notification along with the data and the length of the data transmitted by the server.

Should we wish to un-register for notifications, we can call registerForNotify() again but this time pass NULL as the callback function.

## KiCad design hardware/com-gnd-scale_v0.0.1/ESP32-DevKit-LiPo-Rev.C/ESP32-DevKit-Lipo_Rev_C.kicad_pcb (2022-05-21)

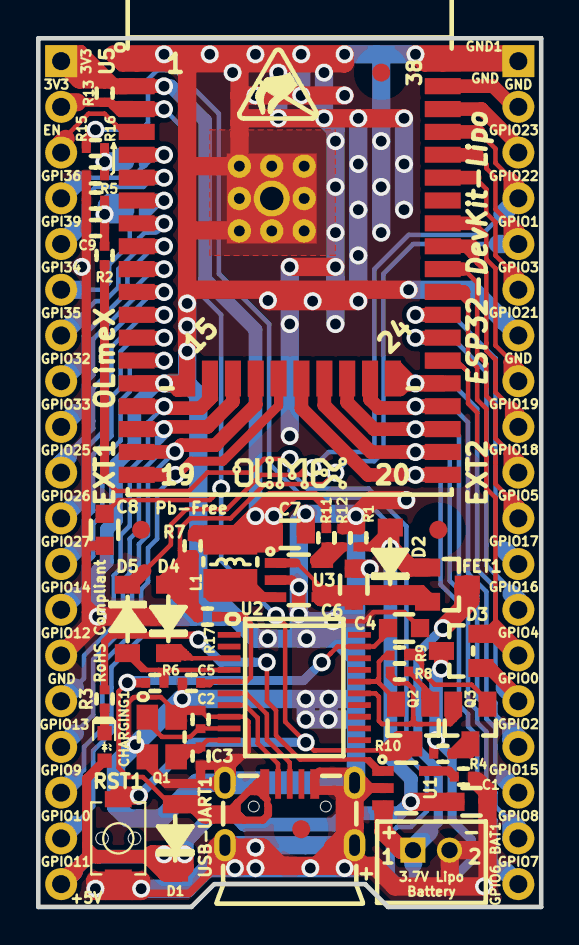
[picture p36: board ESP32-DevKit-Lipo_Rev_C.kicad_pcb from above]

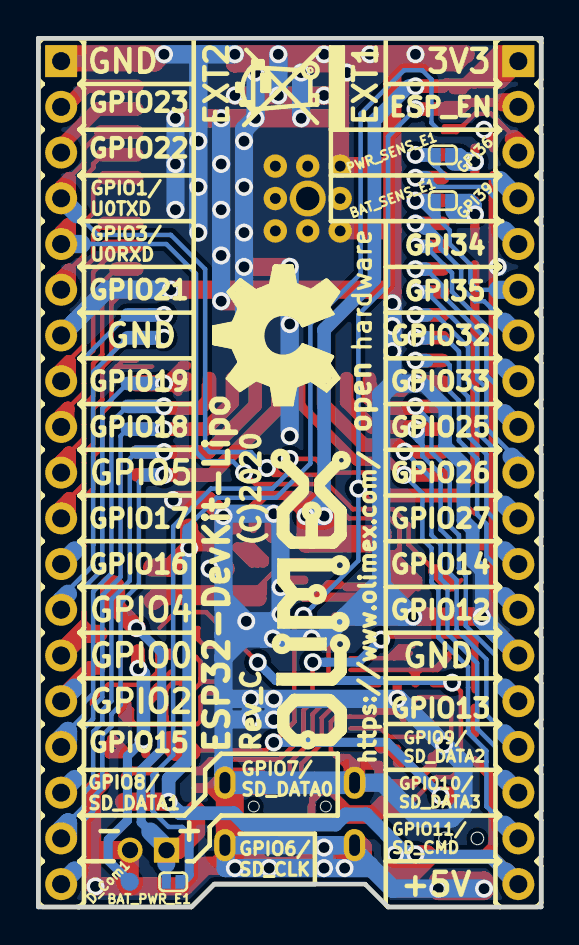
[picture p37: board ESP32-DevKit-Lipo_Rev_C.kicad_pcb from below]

Board: 2 copper layers, 27.9 x 48.3 mm, 59 parts (9 on the bottom side), 60 nets.

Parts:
BAT1: DW02S; LIPO_BAT_VERTICAL_DW02S
BAT_PWR_E1: Opened; SJ_1_SMALLER
BAT_SENS_E1: Opened; SJ_1_SMALLER
C1, C4, C6, C7: 22uF/6.3V/20%/X5R/C0603; C_0603_5MIL_DWS
C2, C3: 27pF/50V/5%/C0G/C0402; C_0402_5MIL_DWS
C5, C9: 100nF/10V/10%/X7R/C0402; C_0402_5MIL_DWS
C8: 1uF/10V/10%/X5R/C0603; C_0603_5MIL_DWS
CHARGING1: LED/YELLOW/0603; LED_0603_KA
D1, D2, D4, D5: 1N5819S4/SOD123; SOD-123_1C-2A_KA
D3: BAT54C(SOT23-3); SOT23-3
D_Com1: TESTPAD; TESTPAD_40-ROUND
EXT1, EXT2: HN1x19
FET1: WPM2015-3/TR; SOT23
FID1, FID2, FID3, FID4: Fiducial; Fiducial1x3
GND1: TESTPAD; TESTPAD_40-ROUND
L1: 2.2uH/1.5A/DCR=72mR/20%/3.00x3.00x1.50mm/CD32(NR3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; CD32
Logo_OSHW: LOGO_OPENHARDWARE_8x8
Olimex_Logo_Big: OLIMEX_LOGO_TB
Olimex_Logo_Small: LOGO_OLIMEX_80
PWR_SENS_E1: Opened; SJ_1_SMALLER
Q1: Q12MHz/20pF/10ppm/4P/3.2x2.5mm; TSX-3.2x2.5mm_GND(3)
Q2, Q3: BC817-40(SOT23); SOT23
R1, R6, R13, R17: 10k/R0402; R_0402_5MIL_DWS
R2, R5, R16: 470k/R0402; R_0402_5MIL_DWS
R3, R4, R8, R9: 2.2k/R0402; R_0402_5MIL_DWS
R7: NA/R0402; R_0402_5MIL_DWS
R10: 220R/R0402; R_0402_5MIL_DWS
R11, R15: 220k/R0402; R_0402_5MIL_DWS
R12: 49.9k/1%/R0402; R_0402_5MIL_DWS
RST1: IT-1185AU2-160G-G-TR; IT1185AU2_V2
Sign_Antistatic: Val**; LOGO_ANTISTATIC_SMALL_4.5mmX2.8mm
Sign_RecycleBin: LOGO_RECYCLEBIN_1
U1: BL4054B-42TPRN(SOT23-5); SOT-23-5
U2: CH340T(SSOP20W); SSOP-20W
U3: SY8089AAAC(SOT23-5); SOT-23-5
U5: ESP32-WROOM-32D-4MB; ESP32-WROVER_MODULE
USB-UART1: MISB-SWMM-5B-LF(USB_MICRO); USB-MICRO_MISB-SWMM-5B_LF

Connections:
+3V3: C7.1, EXT1.1, L1.2, R7.2, R11.2, R13.1, U5.2
+5V: C1.1, CHARGING1.2, D1.1, D2.2, EXT1.19, FET1.1, R1.1, R15.1, U1.4
/+5V_USB: C4.1, D1.2, R6.1, U2.19, USB-UART1.1
/D_Com: D3.3, D_Com1.1, R10.2
/ESP_EN: C8.1, EXT1.2, Q2.3, R13.2, RST1.1, U5.3
/GPI34: EXT1.5, U5.6
/GPI35: BAT_SENS_E1.2, EXT1.6, U5.7
/GPI36\SENSOR_VP: EXT1.3, U5.4
/GPI39\SENSOR_VN: EXT1.4, PWR_SENS_E1.2, U5.5
/GPIO0: D3.2, EXT2.14, U5.25
/GPIO1\U0TXD: D5.1, EXT2.4, U5.35
/GPIO2: D3.1, EXT2.15, U5.24
/GPIO3\U0RXD: D4.2, EXT2.5, R7.1, R17.2, U5.34
/GPIO4: EXT2.13, U5.26
/GPIO5: EXT2.10, U5.29
/GPIO6\SD_CLK: EXT2.19, U5.20
/GPIO7\SD_DATA0: EXT2.18, U5.21
/GPIO8\SD_DATA1: EXT2.17, U5.22
/GPIO9\SD_DATA2: EXT1.16, U5.17
/GPIO10\SD_DATA3: EXT1.17, U5.18
/GPIO11\SD_CMD: EXT1.18, U5.19
/GPIO12: EXT1.13, U5.14
/GPIO13: EXT1.15, U5.16
/GPIO14: EXT1.12, U5.13
/GPIO15: EXT2.16, U5.23
/GPIO16: EXT2.12, U5.27
/GPIO17: EXT2.11, U5.28
/GPIO18: EXT2.9, U5.30
/GPIO19: EXT2.8, U5.31
/GPIO21: EXT2.6, U5.33
/GPIO22: EXT2.3, U5.36
/GPIO23: EXT2.2, U5.37
/GPIO25: EXT1.9, U5.10
/GPIO26: EXT1.10, U5.11
/GPIO27: EXT1.11, U5.12
/GPIO32: EXT1.7, U5.8
/GPIO33: EXT1.8, U5.9
GND: BAT1.2, C1.2, C2.2, C3.2, C4.2, C5.2, C6.2, C7.2, C8.2, C9.1, EXT1.14, EXT2.1, EXT2.7, GND1.1, Q1.3, R1.2, R4.2, R5.2, R12.2, R16.2, RST1.2, U1.2, U2.8, U3.2, U5.1, U5.15, U5.38, U5.39, USB-UART1.0, USB-UART1.5
unnamed: BAT_PWR_E1.1, R2.1
unnamed: BAT_SENS_E1.1, C9.2, R2.2, R5.1
unnamed: C2.1, Q1.1, U2.9
unnamed: C3.1, Q1.2, U2.10
unnamed: C5.1, R17.1, U2.5
unnamed: C6.1, D2.1, FET1.2, U3.1, U3.4
unnamed: CHARGING1.1, R3.1
unnamed: D4.1, U2.3
unnamed: D5.2, R6.2, U2.4
unnamed: L1.1, U3.3
unnamed: PWR_SENS_E1.1, R15.2, R16.1
unnamed: Q2.1, R8.2
unnamed: Q2.2, R9.1, U2.16
unnamed: Q3.1, R9.2
unnamed: Q3.2, R8.1, U2.15
unnamed: Q3.3, R10.1
unnamed: R3.2, U1.1
unnamed: R4.1, U1.5
unnamed: R11.1, R12.1, U3.5
unnamed: U2.6, USB-UART1.3
unnamed: U2.7, USB-UART1.2
VBAT: BAT1.1, BAT_PWR_E1.2, FET1.3, U1.3

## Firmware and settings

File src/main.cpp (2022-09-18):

#include <Arduino.h>
#include <Wire.h>
#include <SPI.h>

// https://github.com/nkolban/ESP32_BLE_Arduino
#include <BLEDevice.h>
#include <BLEUtils.h>
#include <BLEServer.h>
#include <BLE2902.h>
#include <ADS126X.h>
#include <definitions/ADS126X_hardware.h> // board specific commands

#include <Smoothed.h>

#include "scale.h"

// https://btprodspecificationrefs.blob.core.windows.net/assigned-values/16-bit%20UUID%20Numbers%20Document.pdf
/**
 * GATT Characteristic and Object Type 0x2A6D Pressure (spec says unit is pascals)
 * GATT Unit 0x2780 bar
 * GATT Unit 0x272F Celsius temperature (degree Celsius)
 * GATT Characteristic and Object Type 0x2A1C Temperature Measurement
 * GATT Characteristic and Object Type 0x2A1D Temperature Type
 */
#define SERVICE_UUID "8fc1ceca-b162-4401-9607-c8ac21383e4e"
#define PRESSURE_SENSOR_CHAR_ID "c14f18ef-4797-439e-a54f-498ba680291d" // BT read-only characteristic for pressure sensor value in bars
#define PRESSURE_TARGET_CHAR_ID "34c242f1-8b5f-4d99-8238-4538eb0b5764" // BT read/write characteristic for target pressure in bars
#define PUMP_POWER_CHAR_ID "d8ad3645-50ad-4f7a-a79d-af0a59469455"      // BT read-only characteristic for pumps power level
#define TEMP_SENSOR_CHAR_ID 0x2A1C                                     // BT read-only characteristic for boiler external temperature
#define FLOW_SENSOR_CHAR_ID "f5ec47c3-b240-49e8-a7c8-1b5fe5537cde"     // BT read-only characteristic for in-flow rate
#define BARS_UNIT_ID "2780"

Scale comGndScale;

/**
 * Pins
 * set-up for ESP32 Devkit-c
 * see: https://circuits4you.com/2018/12/31/esp32-wroom32-devkit-analog-read-example/)
 */

/**
 * SPI - ESP32-devkit-c standard outputs for VSPI
 * ESP32    ADS1262           ESP32 VSPI Std Pin
 * ==============================================
 * SPID =   MOSI = data out - VSPI uses GPIO23
 * SPIQ =   MISO = data in  - VSPI uses GPIO19
 * VSPIWP = START           - VSPI uses GPIO22
 * CK =     CLK             - VSPI uses GPIO18
 * CS =     CS              - VSPI uses GPIO5
 */
// const int spiCs = 5;           // SPI CS pin
// const int spiStart = 22;       // SPI Start pin
// const int esp32AdcRdyPin = 17; // ADS126X RDY pin (14) -> ESP32 io pin (active low)

/**
 * HSFPAR303A force sensor
 * Force sensor is connected to GNDA and +4VA through SPDT
 * Alternating Polarity Circuit (aka "AC Excitation Circuit").
 * Pin 1 vdd Exc +/- -> Exc1 (SPDT)
 * pin 2 v1  Out +/- -> ADC AINx
 * pin 3 v2  Out -/+ -> ADC AINx+1
 * pin 4 gnd Exc -/+ -> Exc2 (SPDT)
 */

/**
 * DG2733E SPDT Switch
 * Used as an H-Bridge to alternate the polarity of the Force Sensors'
 * Excitation Voltage.
 * Pin 1 V+   -> +4VA
 * Pin 2 NO1  -> +4VA
 * Pin 3 COM1 -> Exc1 (Force Sensor Pin 1)
 * Pin 4 IN   -> EXCCTRL - ESP32 GPIO 25
 * Pin 5 NC1  -> GNDA
 * Pin 6 GND  -> GNDA
 * Pin 7 NC2  -> +4VA
 * Pin 8 EN   -> EXCEN - ESP32 GPIO26
 * Pin 9 COM2 -> Exc2 (Force Sensor pin 4)
 * Pin 10 N02 -> GNDA
 */

float lastGrams = 0;
float grams = 0;
Smoothed<float> voltageSmoother;

/**
 * Bluetooth Globals
 */
bool deviceConnected = false;
bool oldDeviceConnected = false;
BLEServer *pServer = NULL;
BLECharacteristic *pPressureSensorBLEChar = NULL;
BLECharacteristic *pPressureTargetBLEChar = NULL;
BLECharacteristic *pPumpPowerBLEChar = NULL;
BLECharacteristic *pTemperatureSensorBLEChar = NULL;
BLECharacteristic *pFlowSensorBLEChar = NULL;

// https://github.com/nkolban/ESP32_BLE_Arduino/blob/master/examples/BLE_notify/BLE_notify.ino
class ComGndServerCallbacks : public BLEServerCallbacks
{
  void onConnect(BLEServer *pServer)
  {
    Serial.println("BLE Server connected");
    deviceConnected = true;
  };

  void onDisconnect(BLEServer *pServer)
  {
    Serial.println("BLE Server Disconnected");
    deviceConnected = false;
  }
};
// https://learn.sparkfun.com/tutorials/esp32-thing-plus-hookup-guide/arduino-example-esp32-ble
class PressureSensorBLECharCallbacks : public BLECharacteristicCallbacks
{
  void onRead(BLECharacteristic *pCharacteristic)
  {
  }
};

void bleNotifyTask(void *params)
{
  for (;;)
  {
    vTaskDelay(100 / portTICK_PERIOD_MS);
  }
}

/**
 * Main Setup
 */
void setup()
{

  Serial.begin(115200);
  Serial.println("Setup start");
  Serial.begin(115200);

  // flow sensor support 100k and 400k freq
  // I2C.begin(i2cSda, i2cScl, 100000);

  BLEDevice::init("COM-GND Scale");
  Serial.println("BLE Device Initialized");
  pServer = BLEDevice::createServer();
  Serial.println("BLE Server Initialized");
  BLEService *pService = pServer->createService(SERVICE_UUID);
  Serial.println("BLE Service Initialized");
  pServer->setCallbacks(new ComGndServerCallbacks());
  Serial.println("BLE Server Callback Initialized");
  pService->start();

  Serial.println("BLE Service Started");

  // BLEAdvertising *pAdvertising = pServer->getAdvertising();  // this still is working for backward compatibility
  BLEAdvertising *pAdvertising = BLEDevice::getAdvertising();
  Serial.println("BLE BLEAdvertising Initialized");

  pAdvertising->addServiceUUID(SERVICE_UUID);
  pAdvertising->setScanResponse(true);
  pAdvertising->setMinPreferred(0x06); // functions that help with iPhone connections issue
  pAdvertising->setMinPreferred(0x12);
  Serial.println("BLE BLEAdvertising Setup Complete");

  BLEDevice::startAdvertising();
  Serial.println("BLE Advertizing Started");
  Serial.println("BLE Setup Complete");

  // pinMode(8, OUTPUT);
  Serial.begin(115200);
  // digitalWrite(8, HIGH);

  comGndScale.begin();
}

void handleCli()
{
  if (Serial.available())
  {
    char input = Serial.read();
    if (input == 'r')
    {
      Serial.println("Reseting Calibration");
      comGndScale.resetCellsCal();
      Serial.println("End Reseting Calibration");
    }
    // Calibrate several times with the weight at each corner to try and
    // find the max and min values for each cell.
    if (input == 'c')
    {
      Serial.println("Start Calibration");

      comGndScale.calCells();

      Serial.println("End Calibration");
    }

    if (input == 't')
    {
      Serial.println("Start Tare");

      comGndScale.tare();

      Serial.println("End Tare");
    }

    if (input == 'x')
    {
      Serial.println("Toggle Bridge Polarity");

      comGndScale.toggleBridge();

      Serial.println("End Toggle Bridge Polarity");
    }
  }
}

/**
 * Main Loop
 */
void loop()
{
  signed long int outputCode = 0;
  const int samples = 1;

  float weightG = comGndScale.readGrams();

  handleCli();
}

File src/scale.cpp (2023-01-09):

#include <Arduino.h>
#include <Plotter.h>
#include "scale.h"

double plotTemp = 0;
double plotG = 0;
Plotter p;

/**
 * Voltage reference pins are AIN0 (pos) and AIN1 (neg)
 * These are connected to the +4VA and GNDA reference voltage outputs
 *
 */
Scale::Scale()
{
    // rdryPin = _rdryPin;
    // spiCsPin = _spiCsPin;
    // spiStartPin = _spiStartPin;
    loadCells[0].posPin = cell0AdcPosPin;
    loadCells[0].negPin = cell0AdcNegPin;
    loadCells[0].nPerMv = (cellFsr / cellMaxLoad) * numberOfCells;
    loadCells[1].posPin = cell1AdcPosPin;
    loadCells[1].negPin = cell1AdcNegPin;
    loadCells[1].nPerMv = (cellFsr / cellMaxLoad) * numberOfCells;
    loadCells[2].posPin = cell2AdcPosPin;
    loadCells[2].negPin = cell2AdcNegPin;
    loadCells[2].nPerMv = (cellFsr / cellMaxLoad) * numberOfCells;
    loadCells[3].posPin = cell3AdcPosPin;
    loadCells[3].negPin = cell3AdcNegPin;
    loadCells[3].nPerMv = (cellFsr / cellMaxLoad) * numberOfCells;
}

Scale::~Scale()
{
}

void Scale::begin()
{
    pinMode(excCtrlPin, OUTPUT);    // SPDT H-Bridge direction control pin
    pinMode(excEnablePin, OUTPUT);  // SPDT H-Bridge enable control pin
    pinMode(rdryPin, INPUT_PULLUP); // adc data ready (RDRY) pin (active low)

    adc.begin(spiCsPin);

    // internal reference is needed when reading internal adc temperature.
    // adc.enableInternalReference();

    /**
     * ADC1 Offset System Calibration
     * The offset system-calibration command corrects ADC1 system offset error.
     * For this type of calibration, externally short the system inputs before the command.
     * When the SYSOCAL1 command is sent, the ADC averages 16 readings to reduce conversion
     * noise for an accurate calibration. When calibration is complete, the offset
     * calibration result is written to the 24-bit offset calibration register (OFCAL[2:0]).
     * The offset calibration register is disabled in chop mode
     **/
    // adc.calibrateSelfOffsetADC1();

    // setup to use external references
    adc.setReference(ADS126X_REF_NEG_AIN1, ADS126X_REF_POS_AIN0);

    // Reset FSCAL coefficients
    adc.REGISTER.FSCAL0.bit.FSCAL = 0x00;
    adc.REGISTER.FSCAL1.bit.FSCAL = 0x00;
    adc.REGISTER.FSCAL2.bit.FSCAL = 0x40;
    adc.writeRegister(ADS126X_FSCAL0);
    adc.writeRegister(ADS126X_FSCAL1);
    adc.writeRegister(ADS126X_FSCAL2);

    // Reset OFCAL coefficients
    adc.REGISTER.OFCAL0.bit.OFC = 0x00;
    adc.REGISTER.OFCAL1.bit.OFC = 0x00;
    adc.REGISTER.OFCAL2.bit.OFC = 0x00;
    adc.writeRegister(ADS126X_OFCAL0);
    adc.writeRegister(ADS126X_OFCAL1);
    adc.writeRegister(ADS126X_OFCAL2);

    adc.setContinuousMode();
    adc.setFilter(ADS126X_SINC1);

    // disable chop mode for AC Bridge Excitation
    adc.setChopMode(ADS126X_CHOP_0);

    adc.setGain(ADS126X_GAIN_32);
    adc.enablePGA();

    // enable H-Bridge
    digitalWrite(excEnablePin, HIGH);

    delay(1000);
    // tare();
    Serial.println(
        "Offsets: " + String(loadCells[0].vOffset) +
        " , " + String(loadCells[1].vOffset) +
        " , " + String(loadCells[2].vOffset) +
        " , " + String(loadCells[3].vOffset));
    adc.setRate(STANDARD_SPS);
    gramsSmoother.begin(SMOOTHED_AVERAGE, 10);

    p.Begin();
    p.AddTimeGraph("Temp", 500, "C", plotTemp);
    p.AddTimeGraph("Weight", 500, "g", plotG);
}

/**
 * Toggle the Voltage Polarity of the ADC
 * This is used for implementing "AC Bridge Excitation" as described in the TI doc:
 * "High-Resolution, Low-Drift, Precision Weigh-Scale Reference Design with AC Bridge Excitation"
 * See: TIDUAC1A.pdf
 * The approach is designed to cancel out systematic sensor error caused by any offset and drift
 * in both the ADC and reference voltage.
 */
void Scale::toggleBridge()
{

    // When bridgeDir == 1, refRef mode is set on the ADC
    uint8_t newMode = bridgeDir == 0 ? 1 : 0;
    setBridgeAcMode(newMode);
}

/**
 * Set the ADC refRev flag.
 * @param refRev - Ref is reverse when refRev == 1;
 */
void Scale::setBridgeAcMode(uint8_t refRev)
{
    bridgeDir = refRev;
    // TODO: It might not be necessary to disable H-Bridge during switching
    // Testing needed.

    // disable H-Bridge Output
    digitalWrite(excEnablePin, LOW);
    // toggle bridge
    digitalWrite(excCtrlPin, bridgeDir);

    adc.setRefRevMode(bridgeDir);

    // enable H-Bridge Output
    digitalWrite(excEnablePin, HIGH);
}

float Scale::readGrams()
{
    float avgG = 0;
    // toggleBridge();
    unsigned long readStartTimestamp = millis();
    for (int i = 0; i < 4; i++)
    {
        updateLoadCellData(loadCells[i], 2);
    }
    for (int i = 0; i < 4; i++)
    {
        avgG += loadCells[i].g;
    }

    // float temp = readTemperature();

    // the weight is the average of the 4 cells.
    avgG /= 4.0;

    unsigned long readEndTimestamp = millis();
    unsigned long readTime = readEndTimestamp - readStartTimestamp;

    // estimate Signal-to-noise-ratio (SNR)
    gramsSmoother.add(avgG);
    float smoothedG = gramsSmoother.get();
    float noise = abs(smoothedG - avgG);
    float snr = log10f(avgG) - log10f(noise);

    Serial.println("t: " + String(readTime) +
                   //    " c " + String(temp, 2) +
                   " sps " + String(1000.0 / readTime) +
                   " g: " + String(avgG) +
                   " avg: " + String(smoothedG) +
                   " noise: " + String(noise, 4) +
                   " snr: " + String(snr, 4) +
                   " : " + String(loadCells[0].g, 6) +
                   " , " + String(loadCells[1].g, 6) +
                   " , " + String(loadCells[2].g, 6) +
                   " , " + String(loadCells[3].g, 6));

    // plotTemp = temp;
    plotG = avgG;

    // p.Plot();

    return avgG;
}

void Scale::updateLoadCellData(loadCell &loadCellData, uint8_t samples = 1)
{
    float v = readAdcV(loadCellData.posPin, loadCellData.negPin, samples);
    float g = vToG(v, loadCellData);
    float n = vToN(v, loadCellData);
    loadCellData.v = v;
    loadCellData.g = g;
    loadCellData.n = n;
}
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

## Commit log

2021-07-30 Basic testing of the TI ads1262 32bit adc with the ALP HSFPAR303A
2021-10-18 Fix SPI <-> I2C pin conflict.
    [main.cpp]
2021-10-19 basic working test to convert adc voltage to grams
2021-11-05 Functional workaround for multi-channel sampling using the ads125x library
    [main.cpp]
2021-11-20 adds code for calibration with reference weight
2021-11-26 enable multi-position calibration and speed optimization testing
2021-12-03 Adds tools for measuring noise response at various ADC settings
    [scale.cpp, scale.h]
2021-12-15 Working ADC temperature reading.
2022-05-21 Layout AC Bridge Schematic Design
    [BAT54.step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]
2022-05-21 Switch to COM-GND fork of ADS126X library.
2022-05-21 Update Schematic
2023-01-09 Fix voltage level on excitation h-bridge pwr. More modifications for isolated testing on the refrev issue.
    [ESP32-DevKit-Lipo_Rev_C.kicad_sch, com-gnd-scale_v0.0.1.kicad_sch]
2023-01-09 Don't track Kicad backup files

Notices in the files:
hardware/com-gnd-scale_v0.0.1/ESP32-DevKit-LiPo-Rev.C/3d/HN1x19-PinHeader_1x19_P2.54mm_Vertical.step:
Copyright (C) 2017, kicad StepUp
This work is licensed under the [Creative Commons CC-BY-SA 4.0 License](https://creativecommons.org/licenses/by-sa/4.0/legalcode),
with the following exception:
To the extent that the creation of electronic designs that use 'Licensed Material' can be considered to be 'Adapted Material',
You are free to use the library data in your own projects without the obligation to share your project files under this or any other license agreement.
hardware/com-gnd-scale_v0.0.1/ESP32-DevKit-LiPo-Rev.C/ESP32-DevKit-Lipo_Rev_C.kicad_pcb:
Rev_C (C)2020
